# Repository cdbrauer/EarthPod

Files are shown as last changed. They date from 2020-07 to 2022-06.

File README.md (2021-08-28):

# EarthPod
Code for the [EarthPod](https://cdbrauer.github.io/research/index.html#earthpod) environmental sensor pod.

## Datalogging-Arduino

### Hardware

The code in this folder is intended to be used in a sensor pod based on a Adafruit Feather M0 Adalogger. Connected sensors include:

| Sensor | [V1](https://github.com/cdbrauer/EarthPod/tree/master/Datalogging-Arduino/feather-sensor-logging-v1) | [V2](https://github.com/cdbrauer/EarthPod/tree/master/Datalogging-Arduino/feather-sensor-logging-v2.1) |
| :--- | :---: | :---: |
| RTC | DS3231 | DS3231 |
| Gyroscope | FXAS21002C | FXAS21002C |
| Acclerometer/Magnetometer | FXOS8700 | FXOS8700 |
| Temperature/Humidity | si7021 | SHT21 |
| Air Pressure/Temperature | BME280 | BMP280 or SPL06-007 |
| Light Level | SI1145 | BH1750 |
| Wind Direction | TCS34725 | N/A |
| Wind Speed | Handheld Anemometer | N/A |

### feather-sensor-logging-v1

*Compatible with V1 only*

This program will create a .csv file on the Adalogger's SD card that records the measurements captured by the sensors. This program is only compatible with the Adafruit Feather M0 Adalogger, and will not fit on the Adafruit Feather 32u4 Adalogger due to memory constraints.

### feather-sensor-logging-v2.1

*Compatible with V2 Only*

This program will create a .csv file on the Adalogger's SD card that records the measurements captured by the sensors. This program is only compatible with the Adafruit Feather M0 Adalogger, and will not fit on the Adafruit Feather 32u4 Adalogger due to memory constraints.

### feather-sensor-tests/SPL06-007

Test I2C communication for an SPL06-007 air pressure and temperature sensor.

### feather-sensor-tests/anemometer

Test initialization and interrupts for a wind speed sensor from a [handheld anemometer](https://www.amazon.com/Anemometer-Velocity-Measurement-Thermometer-Windsurfing/dp/B01JOTJMU6/).

## Datalogging-Python

### Hardware

The code in this folder is intended to be used in a sensor pod based on a Raspberry Pi or Google Coral. The primary
sensing hardware is the Coral Environmental Sensor Board, which provides ambient light, barometric pressure, humidity, and temperature measurements. This board is compatible with both the Google Coral and Raspberry Pi. Additional sensors can be connected to the Environmental Sensor Board through a series of Grove connectors.

### enviro\_logging.py

This program will create a .csv file that records the measurements captured by the sensors in the Environmental Sensor
Board.

### enviro\_logging\_wind.py

This program adds functionality for reading wind speed using the sensor from a [handheld anemometer](https://www.amazon.com/Anemometer-Velocity-Measurement-Thermometer-Windsurfing/dp/B01JOTJMU6/).

### enviro\_logging\_wind\_airflow.py

This program adds functionality for reading wind speed using a [F662 Board Mount Airflow Sensor](https://www.degreec.com/pages/f660-662) from Degree Controls.

## MagnetRelease

### MagnetRelease.ino

Arduino program for the twist-release magnet system used to deploy the pod.

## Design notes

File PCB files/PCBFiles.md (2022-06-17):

This folder contains PCB schematics & layout files.

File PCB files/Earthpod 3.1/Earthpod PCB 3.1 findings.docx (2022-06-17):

Earthpod PCB 3.1 findings

1. The boards should be cleaned / blown off before they’re plugged in, to remove loose solder.

This could cause an accidental intermittent short.

Solder balls on controller 2:

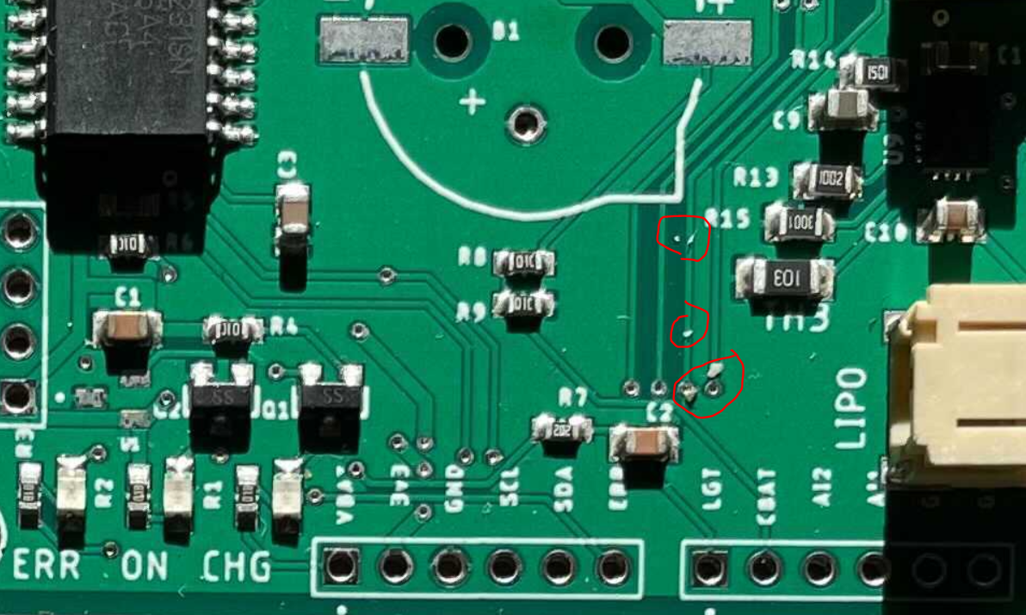
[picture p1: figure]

Solder bridge on controller 8:

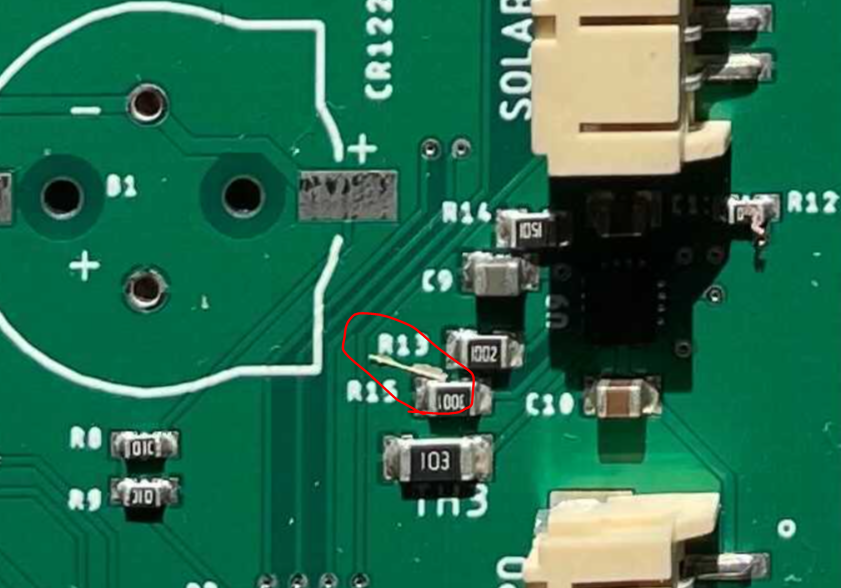
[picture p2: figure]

2. I couldn’t get a good look at this IC on any of the controller boards, but the dot on each chip should be oriented like the markup below (bottom-left corner).

If the dot is not in this orientation, the board should not be plugged in (they messed this up on one board last time).

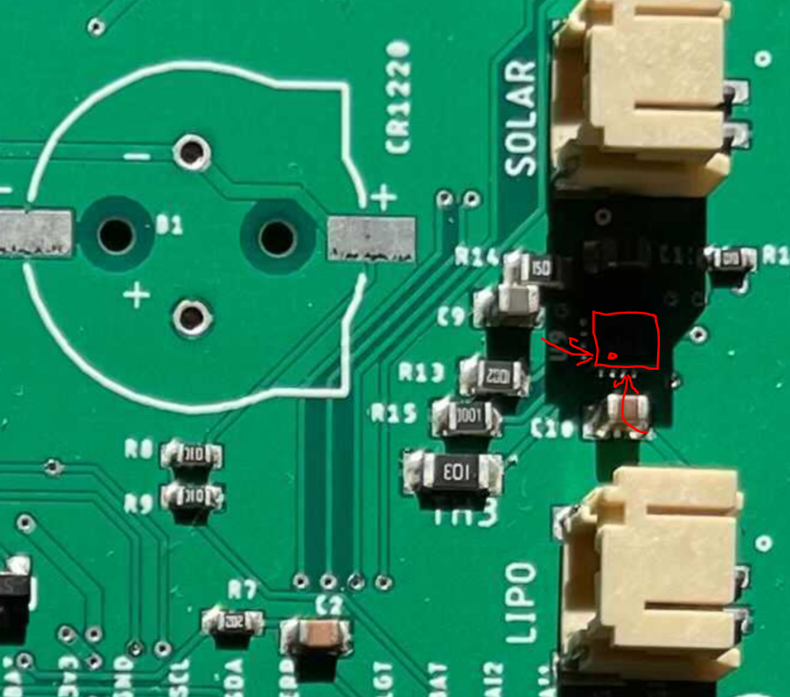
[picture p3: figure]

3. We’ll need to buy a few parts
  - Coin battery connector the RTC
  - Coin battery
  - Hall sensor for the controller board (LEDs will not light up without it)
  - Leaded thermistors for the soil sensor
  - Pin headers

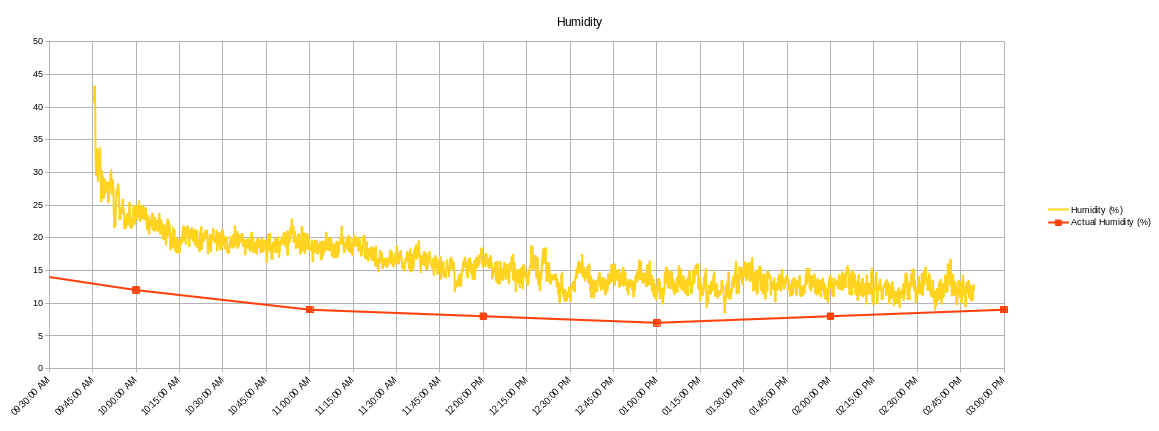
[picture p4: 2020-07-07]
Datalogging-Python/sample-logs/7-6-20/Humidity.png

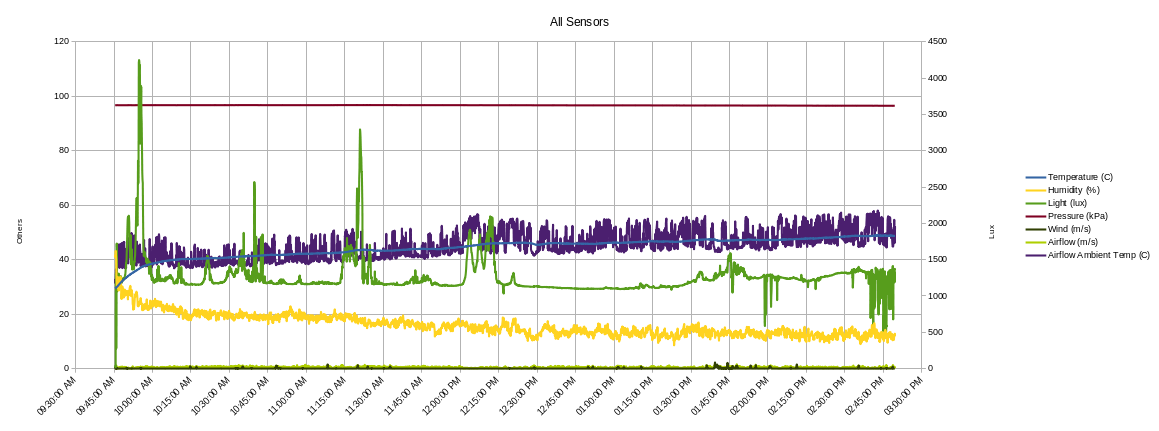
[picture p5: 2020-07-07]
Datalogging-Python/sample-logs/7-6-20/All Sensors.png

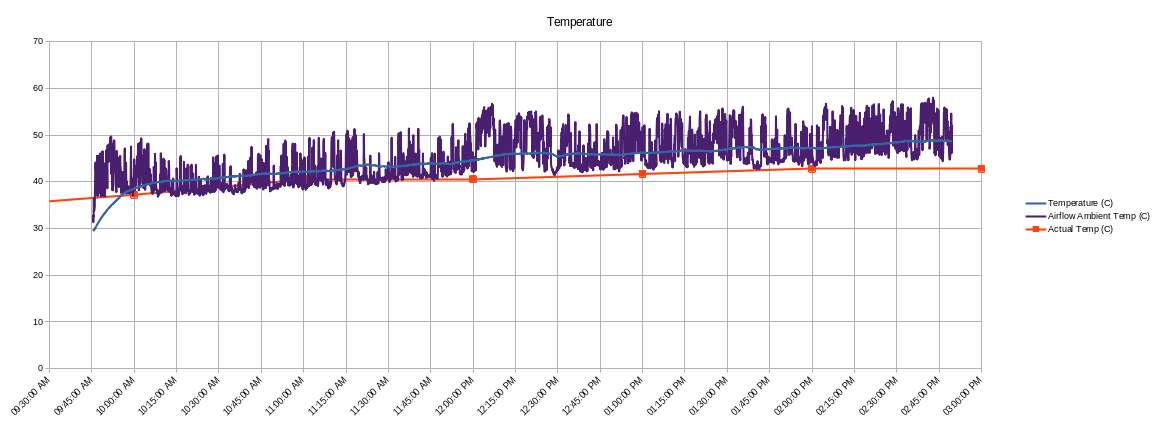
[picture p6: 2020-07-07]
Datalogging-Python/sample-logs/7-6-20/Temperature.png

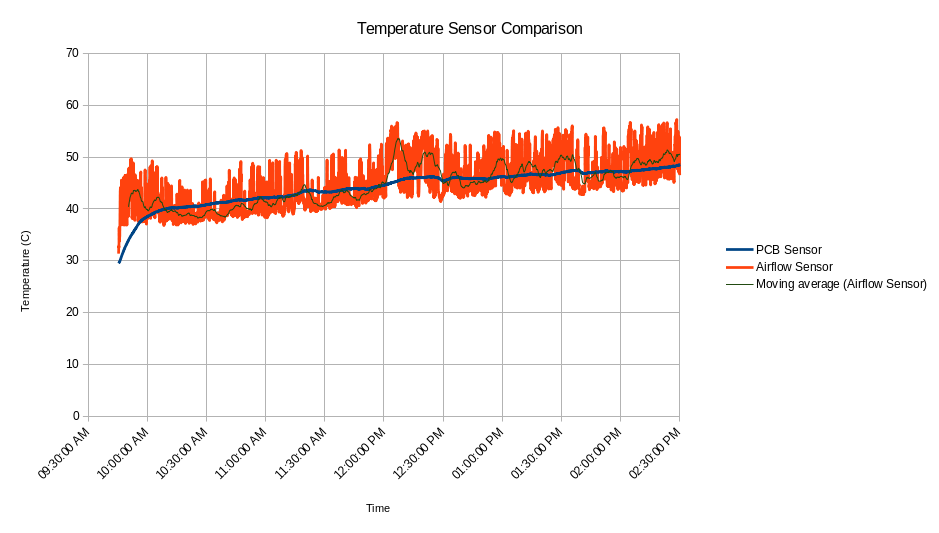
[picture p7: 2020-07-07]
Datalogging-Python/sample-logs/7-6-20/Temp Sensor Comparison.png

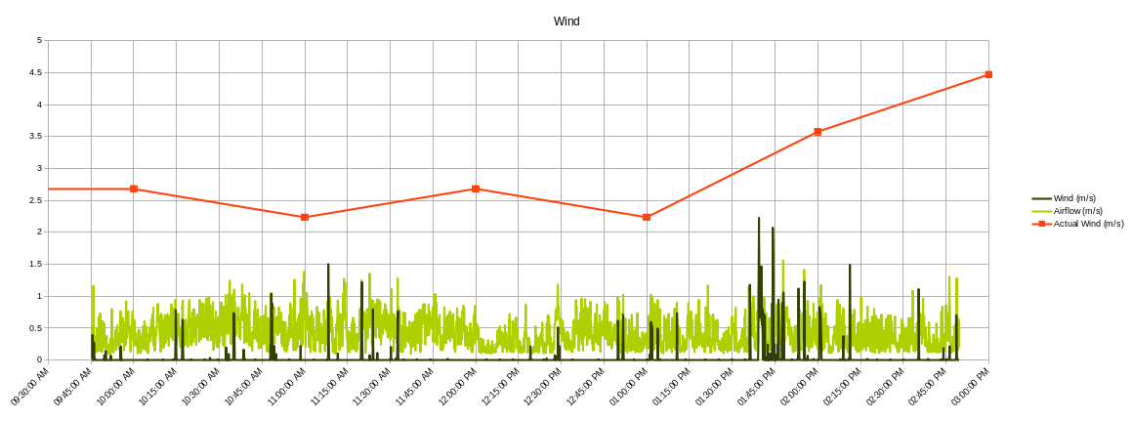
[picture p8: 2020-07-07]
Datalogging-Python/sample-logs/7-6-20/Wind.png

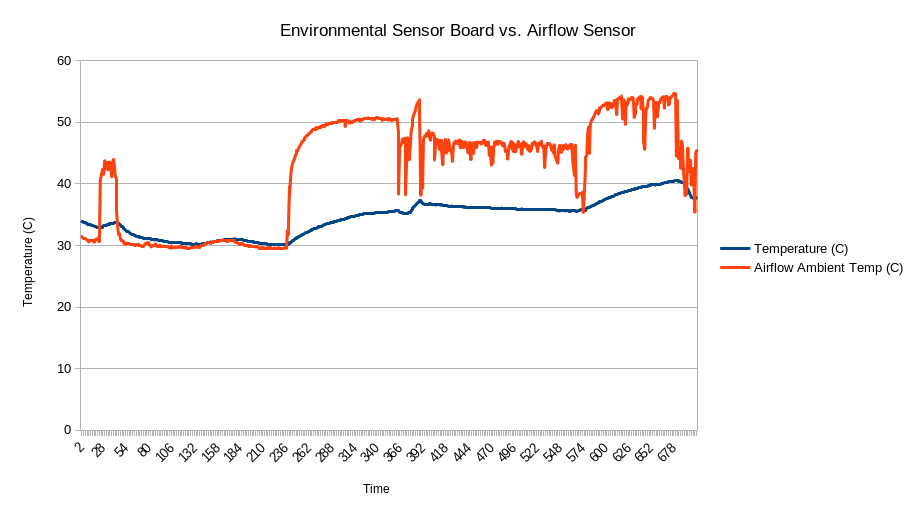
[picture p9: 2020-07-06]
Datalogging-Python/sample-logs/7-5-20/Environmental Sensor Board vs. Airflow Sensor.png

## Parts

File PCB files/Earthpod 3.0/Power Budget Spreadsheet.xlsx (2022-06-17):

DISCHARGING PARAMETERS |  |  |  |  |  |  | CHARGING PARAMETERS
Component | Mfg. Part Number | Voltage (V) | Typical current (mA) | Typical power (mW) | Peak current (mA) | Peak power (mW) | VBAT voltage | Charging current (mA) | Input Power (mW)
Microcontroller | ATSAMD21G18 | 3.3 | 10 | 33 | 98 | 323.4 | 4.2 | 250 | 1050
Wifi Module | ATWINC1500 | 3.3 | 12 | 39.6 | 200 | 660
RTC | DS3231 | 3.3 | 0.2 | 0.66 | 0.2 | 0.66
SD Card* | Any MicroSD card | 3.3 | 30 | 99 | 60 | 198
1 LED | N/A | 3.3 | 0 | 0 | 3.3 | 10.89
Pressure Sensor | SPL06-007 | 3.3 | 0.5 | 1.65 | 0.5 | 1.65
Humidity Sensor | SI7021-A20 | 3.3 | 4 | 13.2 | 4 | 13.2
Gyroscope | FXAS21002C | 3.3 | 2.7 | 8.91 | 2.7 | 8.91
Accelerometer | FXOS8700CQ | 3.3 | 0.575 | 1.8975 | 0.575 | 1.8975
Soil Moisture Sensor | TBD - will be multi-component circuit | 3.3 | 5 | 16.5 | 10 | 33
Light Sensor | TBD | 3.3 | 25 | 82.5 | 25 | 82.5
TOTAL |  |  | 89.975 | 296.9175 | 404.275 | 1334.1075
*SD Card current limits are configurable. 30-60mA is typical. Most mfgrs. do not list current consumption spec.
Here is a good stackexchange post on SD card power consumption. (https://electronics.stackexchange.com/questions/247734/what-determines-the-actual-power-consumption-of-writing-to-a-microsd-card)

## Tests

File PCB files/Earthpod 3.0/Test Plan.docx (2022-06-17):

THINGS TO TEST

Check for shorts to ground from +3.3V, VBAT, VIN, VLIPO

Check IC orientations

One IC is off 90 degrees.

Some silkscreen information missing.

Check for solder bridges

Solar Circuit

- Characterize the VIN signal from the solar panel when in varying amounts of light – is there a lot of fluctuation?
  - Do this with and without the battery.
  - When VIN is around 4.3V or less, DPMM starts. It shouldn’t go lower than this.
- Check that the CHG LED works
- How long will the battery last? Long term test needed.
  - Proper test with solar panels needs to happen in AZ with the housing
  - For now, I can run it in a corner with a fully charged battery and see how long it takes to drain with passive measurements.

Hall Sensor & status LED

- Try magnet in both orientations – do the LEDs turn off when expected?

Moisture Sensor

- Confirm 2.5MHz oscillation
- Test in air and in water, measure the total voltage deflection.
  - Use a wet towel instead of immersing the PCB
  - Adjust resistor values if needed. 1k-10k possible range?
  - Soil capacitance MIGHT range from 1pf to 500 pf
- Are the filters appropriately designed?

Air | No Added Water | Medium Wetness | Lots of water | Just Water | baked

Upload software, change to support new analog signals (2 soil moisture, 2 soil temp, 1 light)

Test humidity sensor with mux

Test Light Sensor analog input

Install temp sensors, test them

Build a sensor network

- Start with a client/server configuration. Scale it up so that any number of sensors (2-4 I guess) can be used.
- Test Wifi power consumption – if continuously streaming, will the battery get drained?

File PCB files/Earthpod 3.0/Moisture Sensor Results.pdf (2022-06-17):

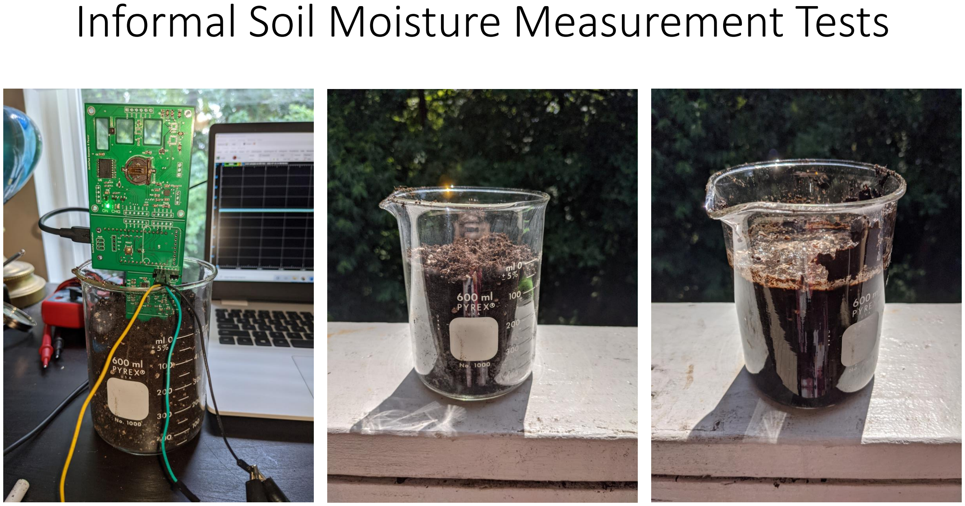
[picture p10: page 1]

Informal Soil Moisture Measurement Tests

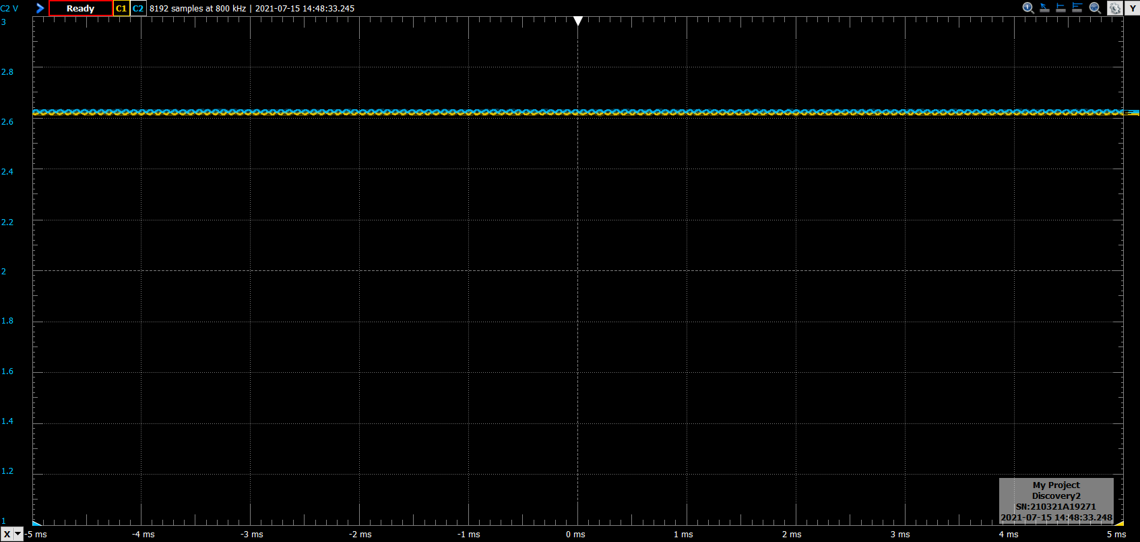
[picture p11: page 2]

Measurement in air – 2.6V

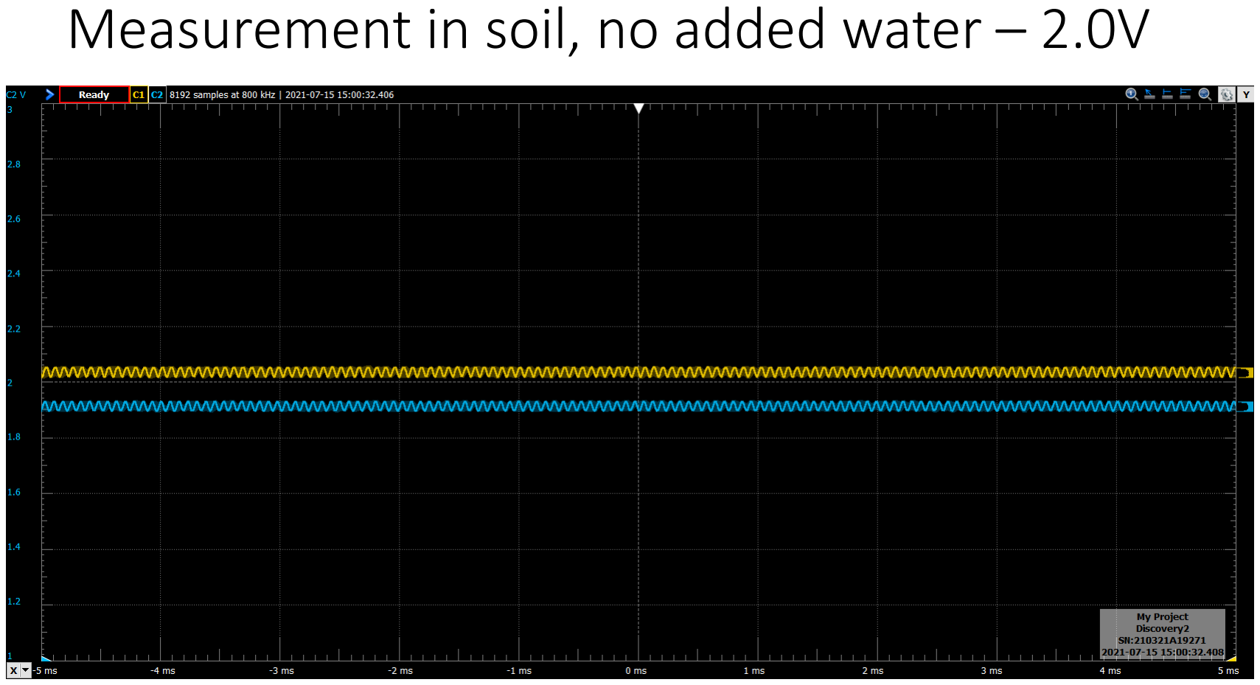
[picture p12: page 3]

Measurement in soil, no added water – 2.0V

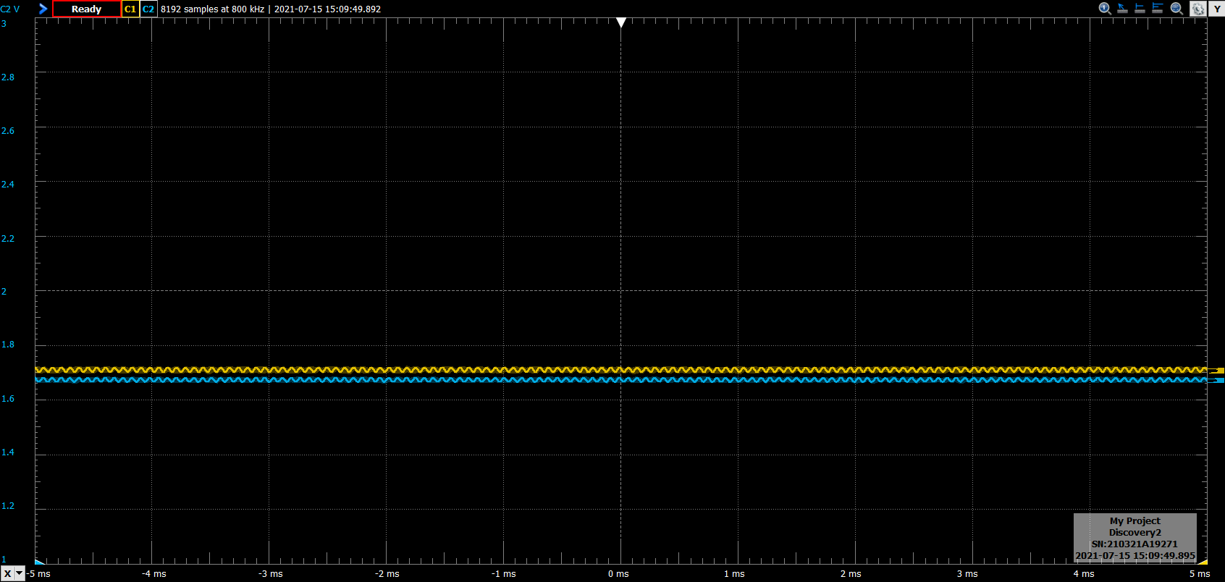
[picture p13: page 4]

Measurement in soil, 150ml water – 1.7V

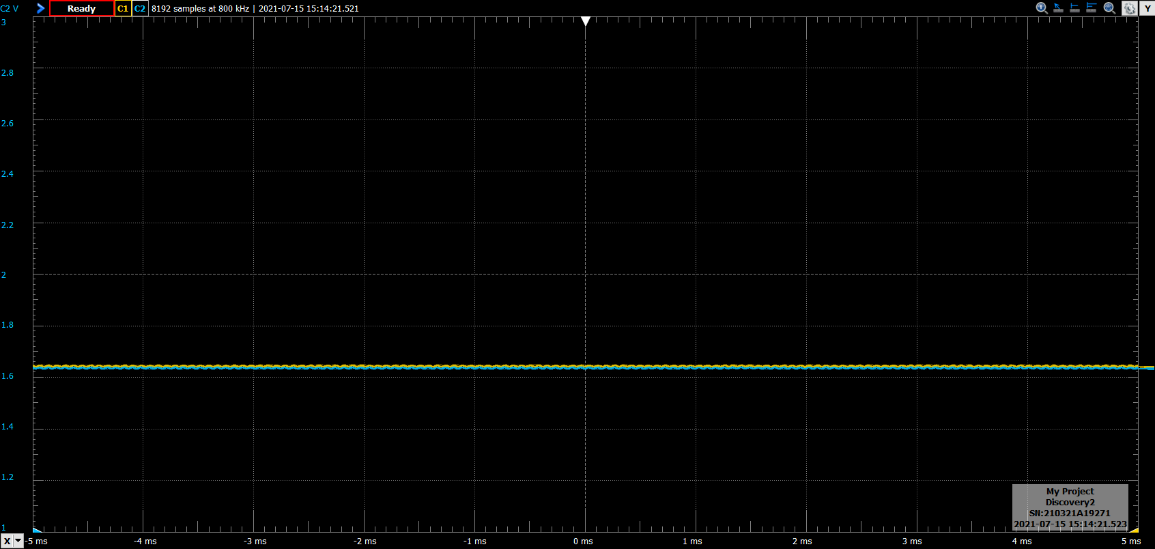
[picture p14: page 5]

Measurement in soil, 300ml water – 1.64V

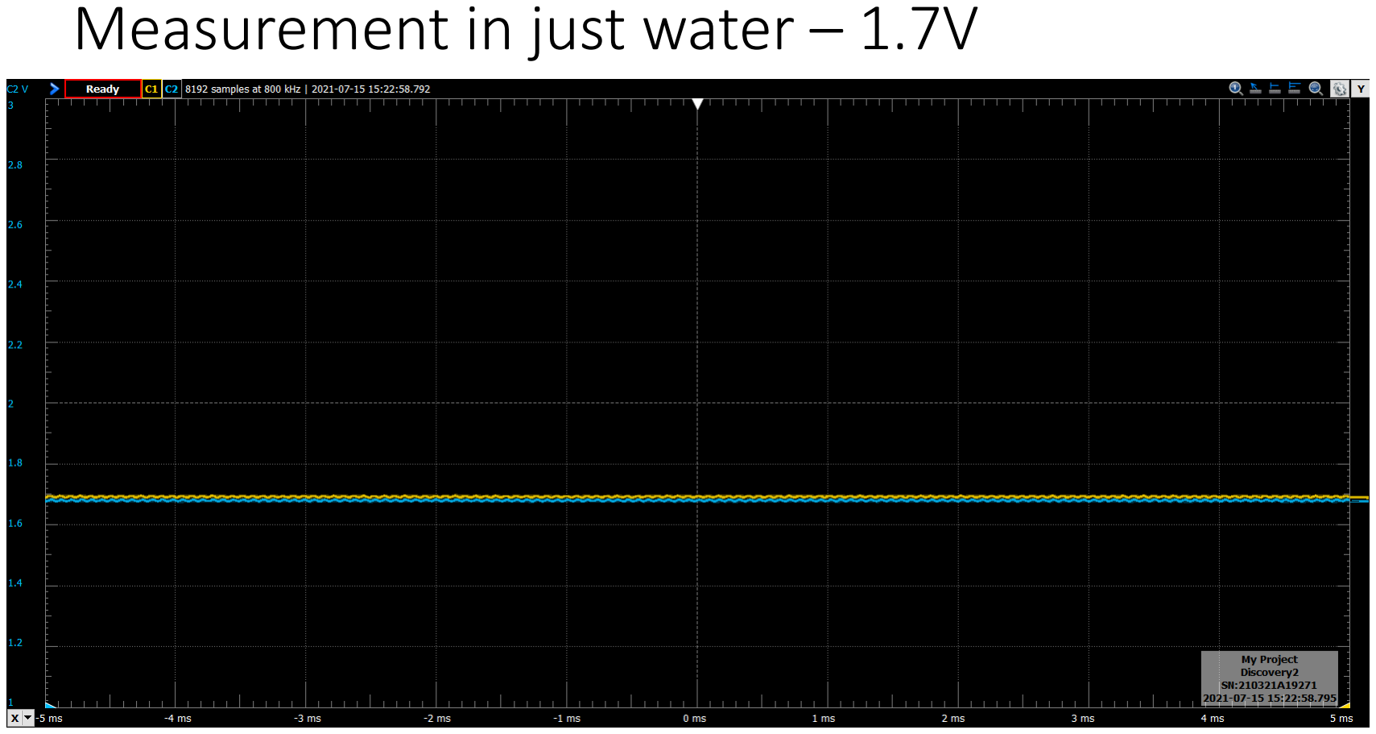
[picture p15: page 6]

Measurement in just water – 1.7V

Measurement after baking – 2.4V

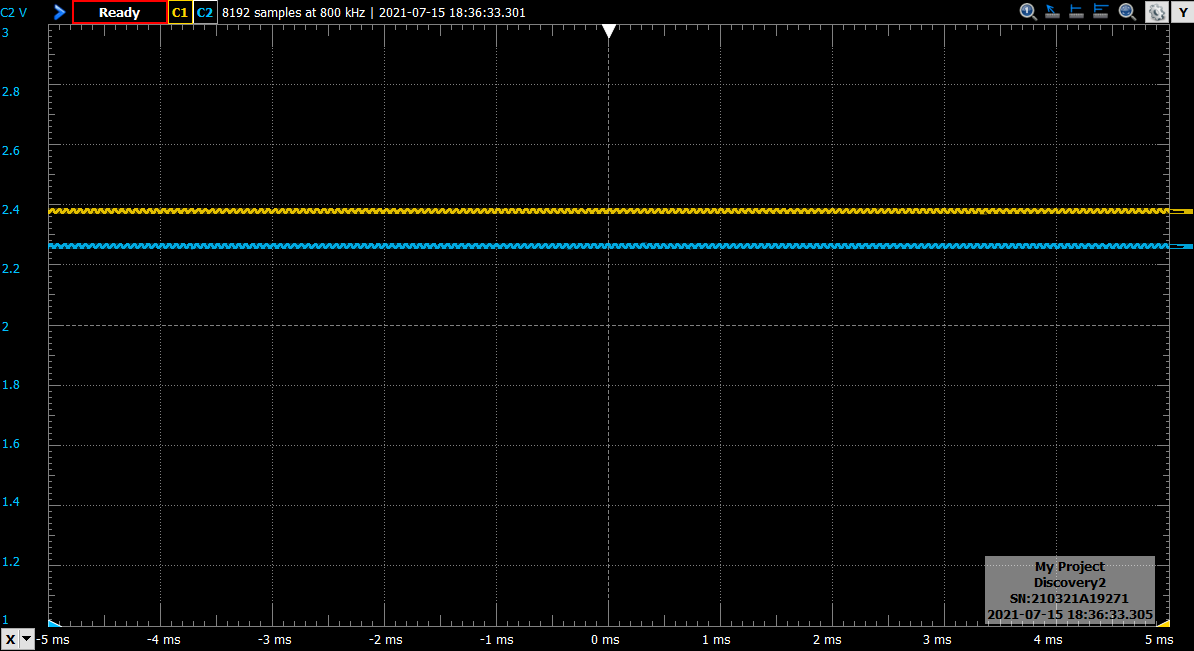
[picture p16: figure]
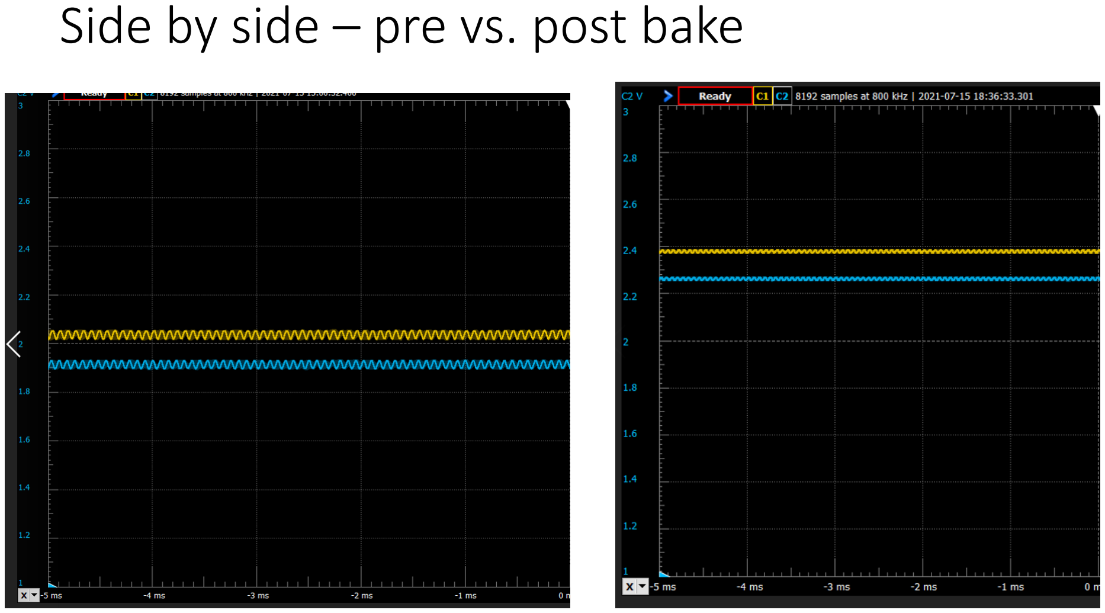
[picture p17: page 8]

Side by side – pre vs. post bake

Details

- Next week:
- Program in Wi-Fi sensor network
- Develop calibration procedure
- Question: will we have some kind of router out in the field?
- Will one pod act as the server, and if so, will storage space for data be an issue?
- Will we just put a laptop out there?
- Decision made: funnel data to a Thingspeak server

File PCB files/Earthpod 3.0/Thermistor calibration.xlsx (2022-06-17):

Temp, C | Resistance, Ohms | Ref. Resistor | Ref. Voltage | Voltage Out | Counts
-40 | 156084 | 4700 | 3.3 | 0.09646482237 | 119.704075 | -36.67082812 | 119.704075
-35 | 112753 |  |  | 0.1320528211 | 163.8655462 | -34.00601167 | 163.8655462
-30 | 82344 |  |  | 0.1781857451 | 221.112311 | -30.68748619 | 221.112311
-25 | 60765 |  |  | 0.2369204919 | 293.9967922 | -26.67694507 | 293.9967922
-20 | 45288 |  |  | 0.3102744659 | 385.0224054 | -21.99053756 | 385.0224054
-15 | 34075 |  |  | 0.4 | 496.3636364 | -16.7167632 | 496.3636364
-10 | 25872 |  |  | 0.5073269659 | 629.546644 | -11.02144593 | 629.546644
-5 | 19814 |  |  | 0.6326996818 | 785.122787 | -5.132257344 | 785.122787
0 | 15300 |  |  | 0.7755 | 962.325 | 0.6982595728 | 962.325
5 | 11909 |  |  | 0.9338310555 | 1158.799446 | 6.24766778 | 1158.799446
10 | 9340 |  |  | 1.104700855 | 1370.833333 | 11.38792987 | 1370.833333
15 | 7378 |  |  | 1.284153005 | 1593.517139 | 16.11634546 | 1593.517139
20 | 5869 |  |  | 1.46749929 | 1821.03321 | 20.54747567 | 1821.03321
25 | 4700 |  |  | 1.65 | 2047.5 | 24.87375367 | 2047.5
30 | 3788 |  |  | 1.82728558 | 2267.495287 | 29.29737341 | 2267.495287
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

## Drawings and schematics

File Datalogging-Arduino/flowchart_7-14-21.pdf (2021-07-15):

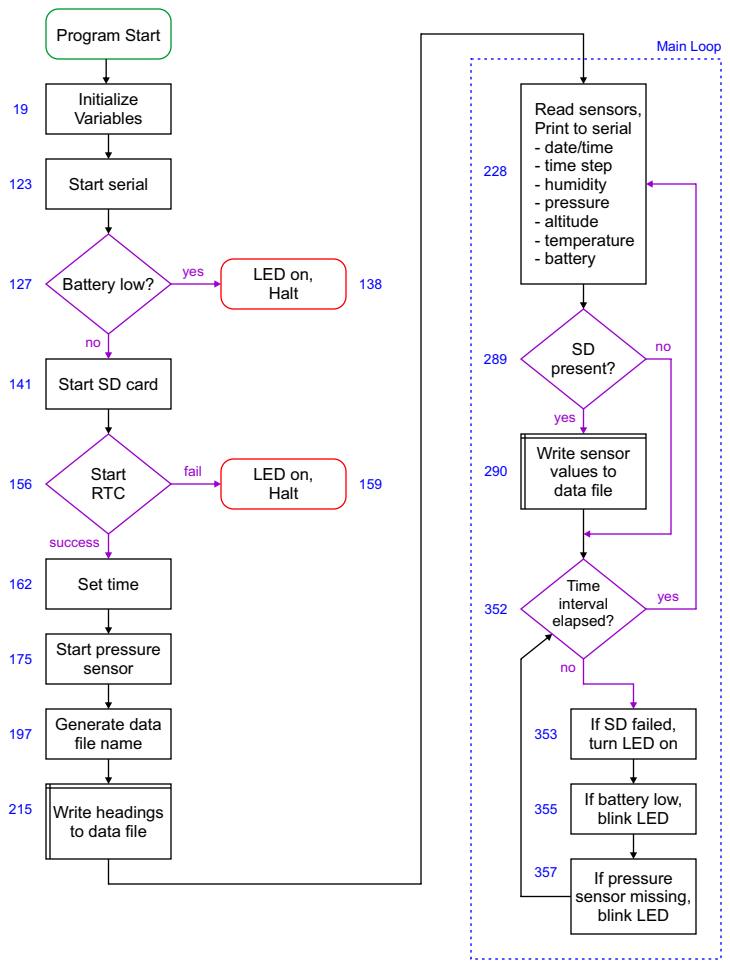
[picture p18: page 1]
Program Start; Initialize Variables; Start serial; Battery low?; LED on,; Halt ¹²⁷; Start SD card; Start RTC; Halt ¹⁵⁶; yes; success; fail; Set time; Start pressure sensor; Main Loop; SD present? ²⁸⁹; Write sensor values to data file; Time interval elapsed?; If pressure sensor missing, blink LED

Read sensors,
Print to serial
- date/time
- time step
- humidity
- pressure
- altitude
- temperature
- battery

Generate data
file name ¹⁹⁷

If SD failed,
turn LED on

If battery low,
blink LED

Write headings
to data file

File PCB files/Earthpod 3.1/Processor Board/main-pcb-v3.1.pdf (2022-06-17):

# GND GND GND 3.3V

## On LED

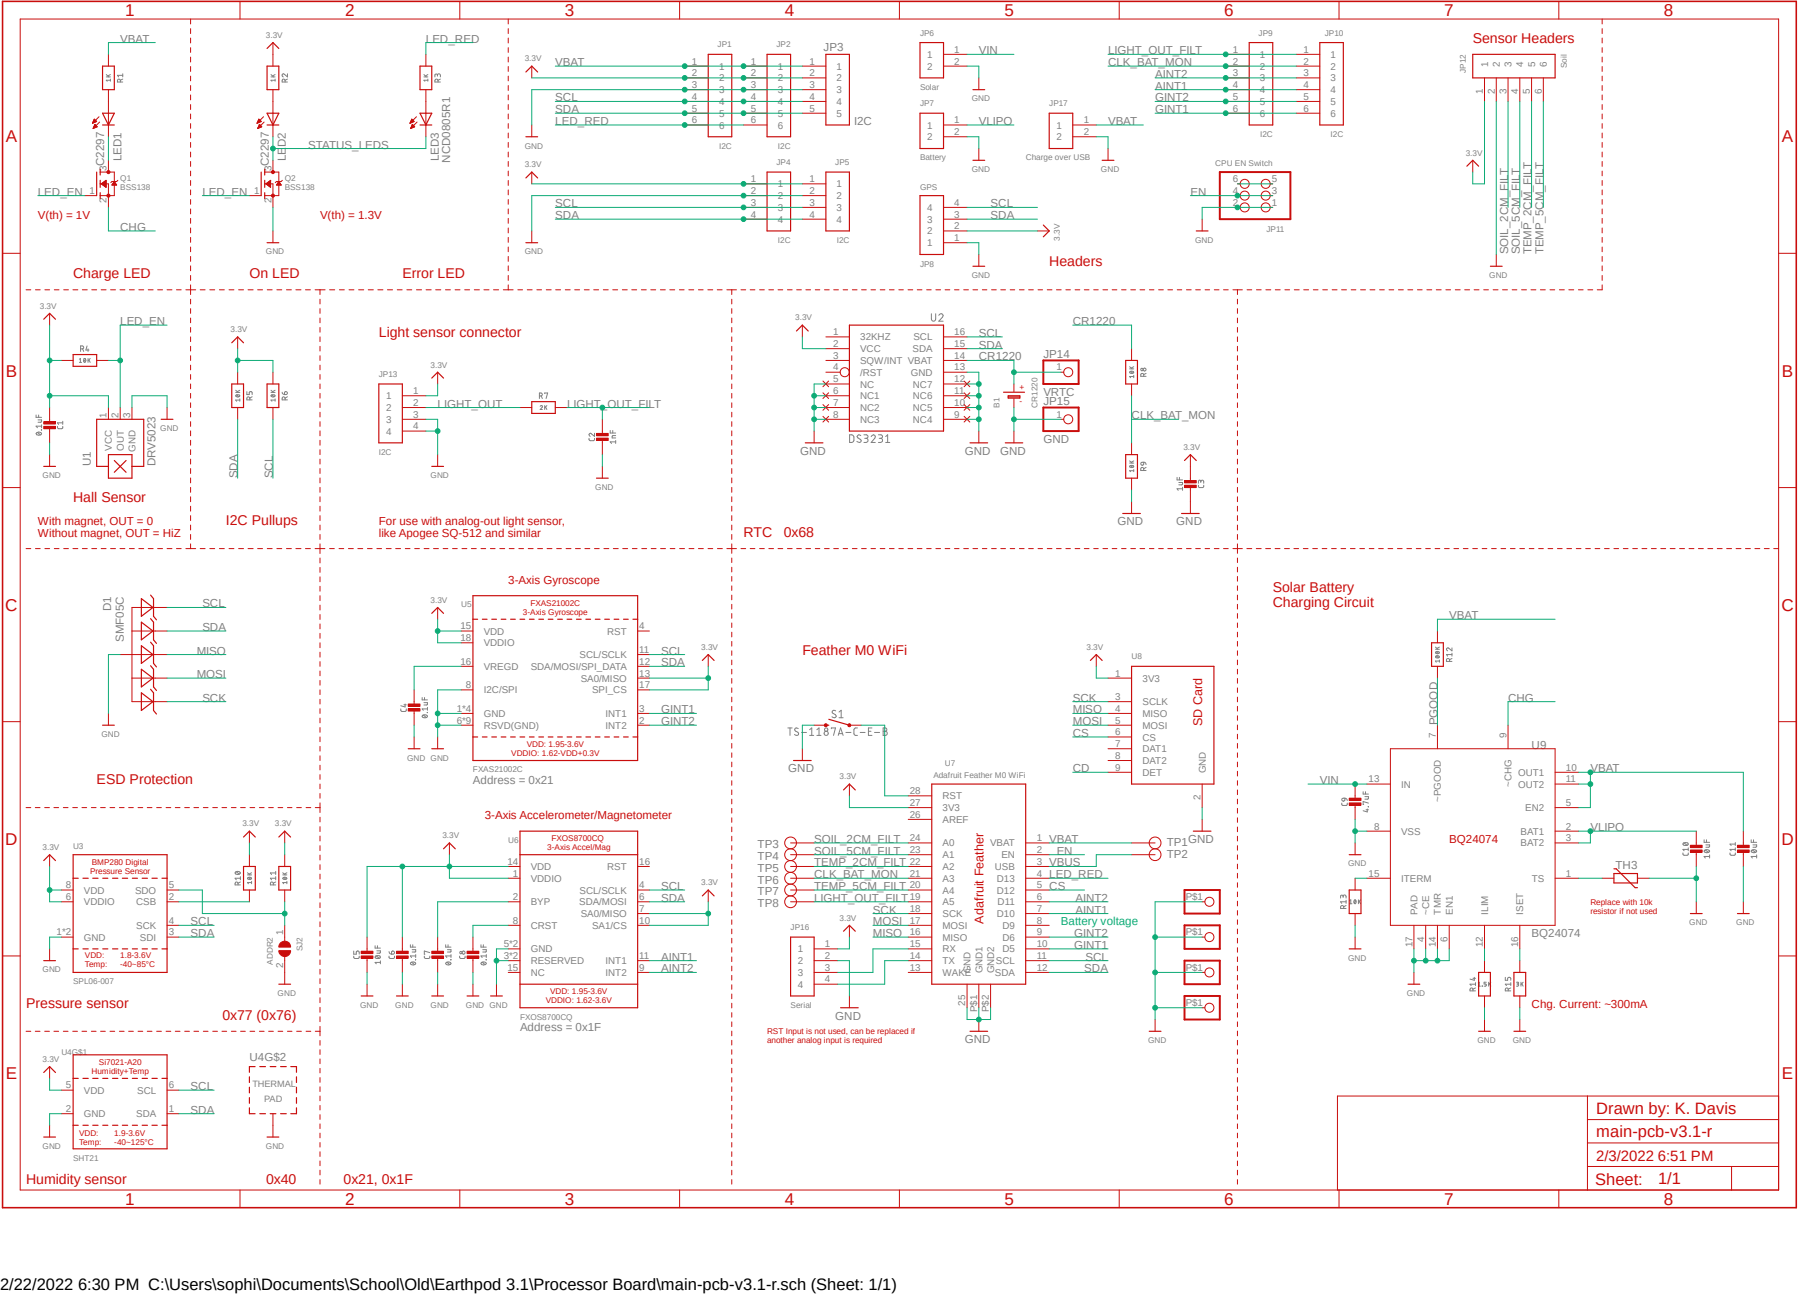
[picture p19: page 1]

Charge over USB GND

With magnet, OUT = 0
Without magnet, OUT = HiZ

For use with analog-out light sensor,
3-Axis Gyroscope VDD: 1.95-3.6V

Feather M0 WiFi
Adafruit Feather M0 WiFi GND

VDDIO: 1.62-VDD+0.3V
3-Axis Accel/Mag VDD: 1.95-3.6V

6 ILIM 12 ISET 16 TS 1 BAT2 3 BAT1 2 EN2 5 OUT2 11 OUT1 10 ~CHG

another analog input is required

2/22/2022 6:30 PM C:\Users\sophi\Documents\School\Old\Earthpod 3.1\Processor Board\main-pcb-v3.1-r.sch (Sheet: 1/1)

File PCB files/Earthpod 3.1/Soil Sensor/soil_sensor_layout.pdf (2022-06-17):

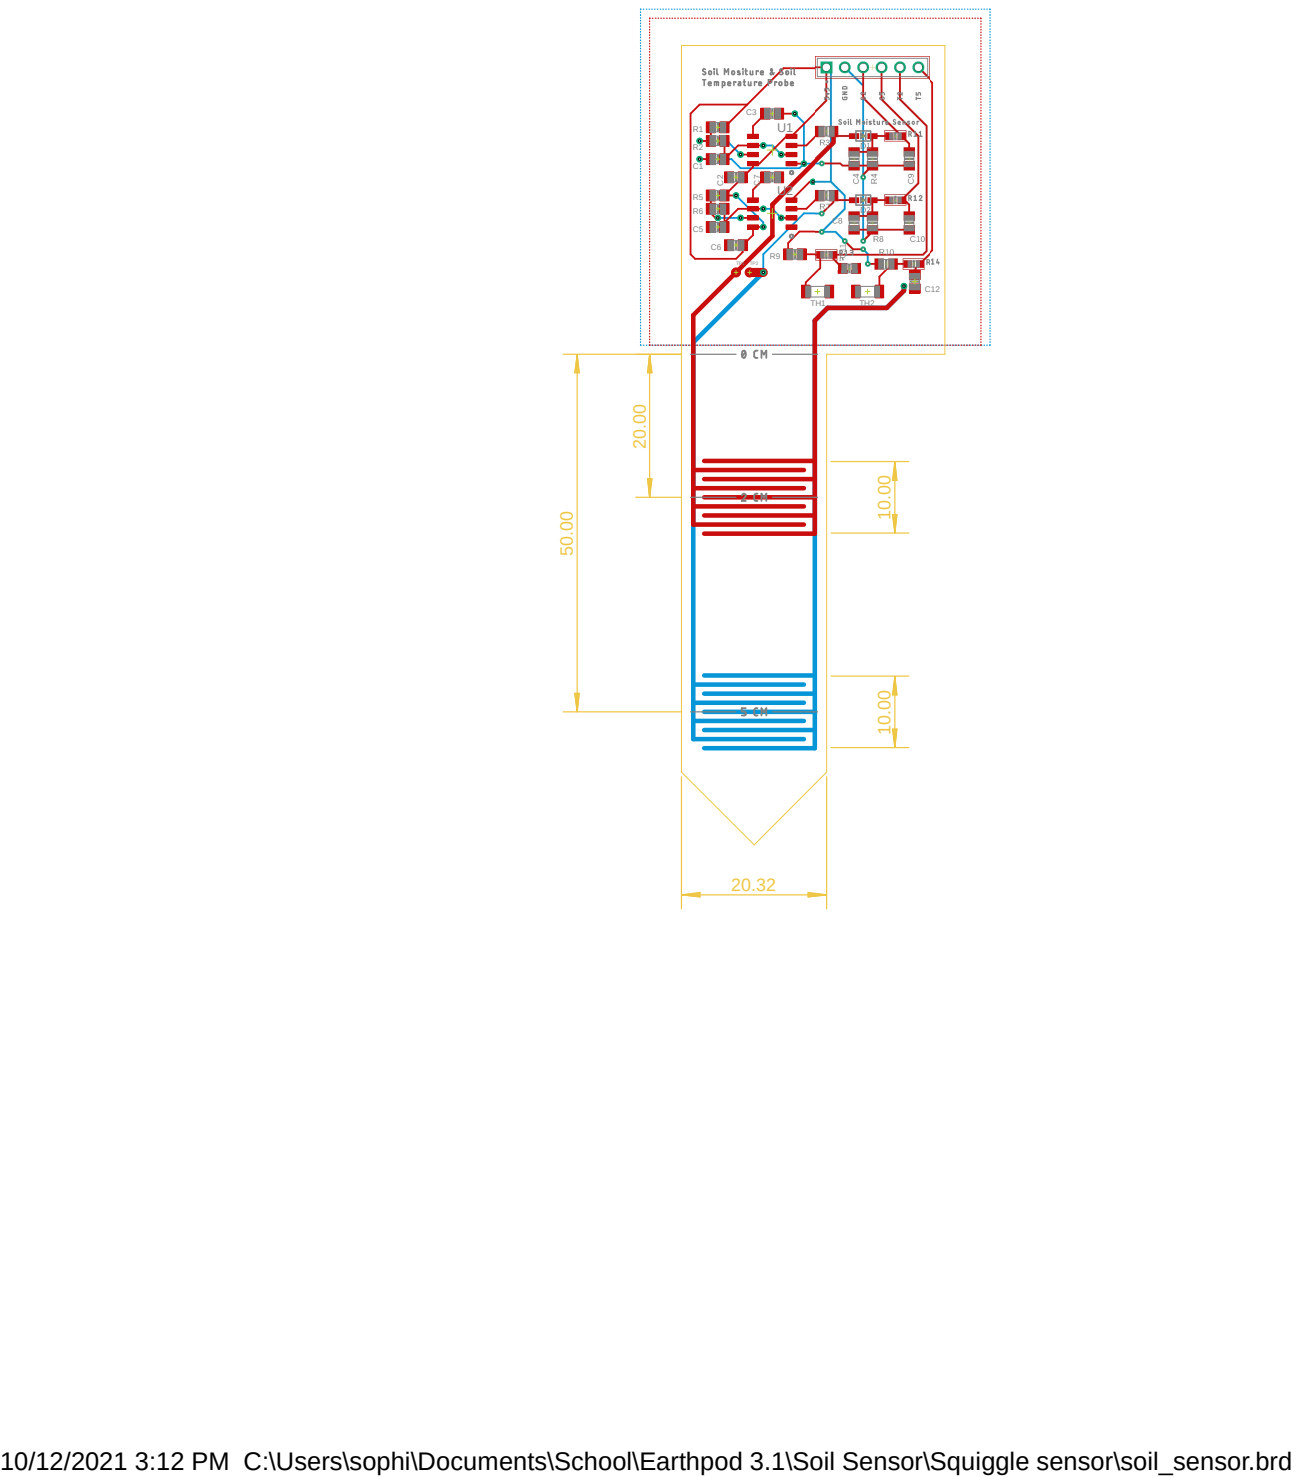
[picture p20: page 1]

10/12/2021 3:12 PM C:\Users\sophi\Documents\School\Earthpod 3.1\Soil Sensor\Squiggle sensor\soil_sensor.brd

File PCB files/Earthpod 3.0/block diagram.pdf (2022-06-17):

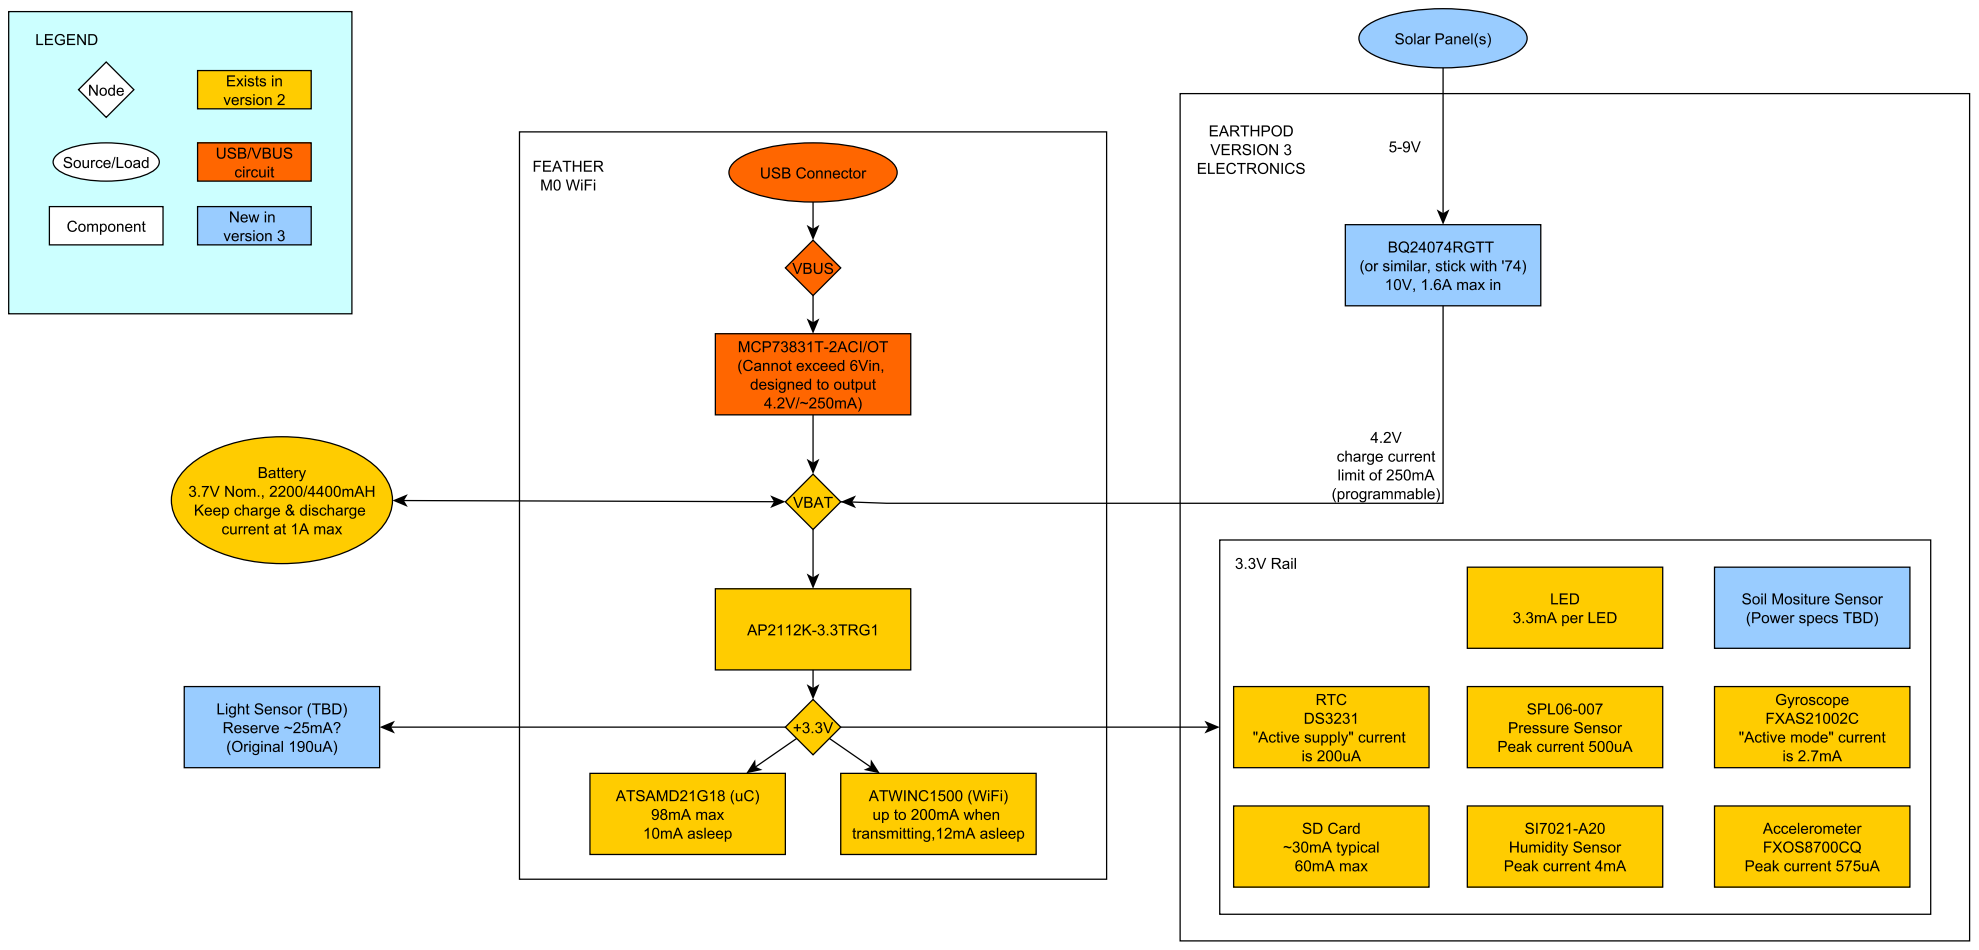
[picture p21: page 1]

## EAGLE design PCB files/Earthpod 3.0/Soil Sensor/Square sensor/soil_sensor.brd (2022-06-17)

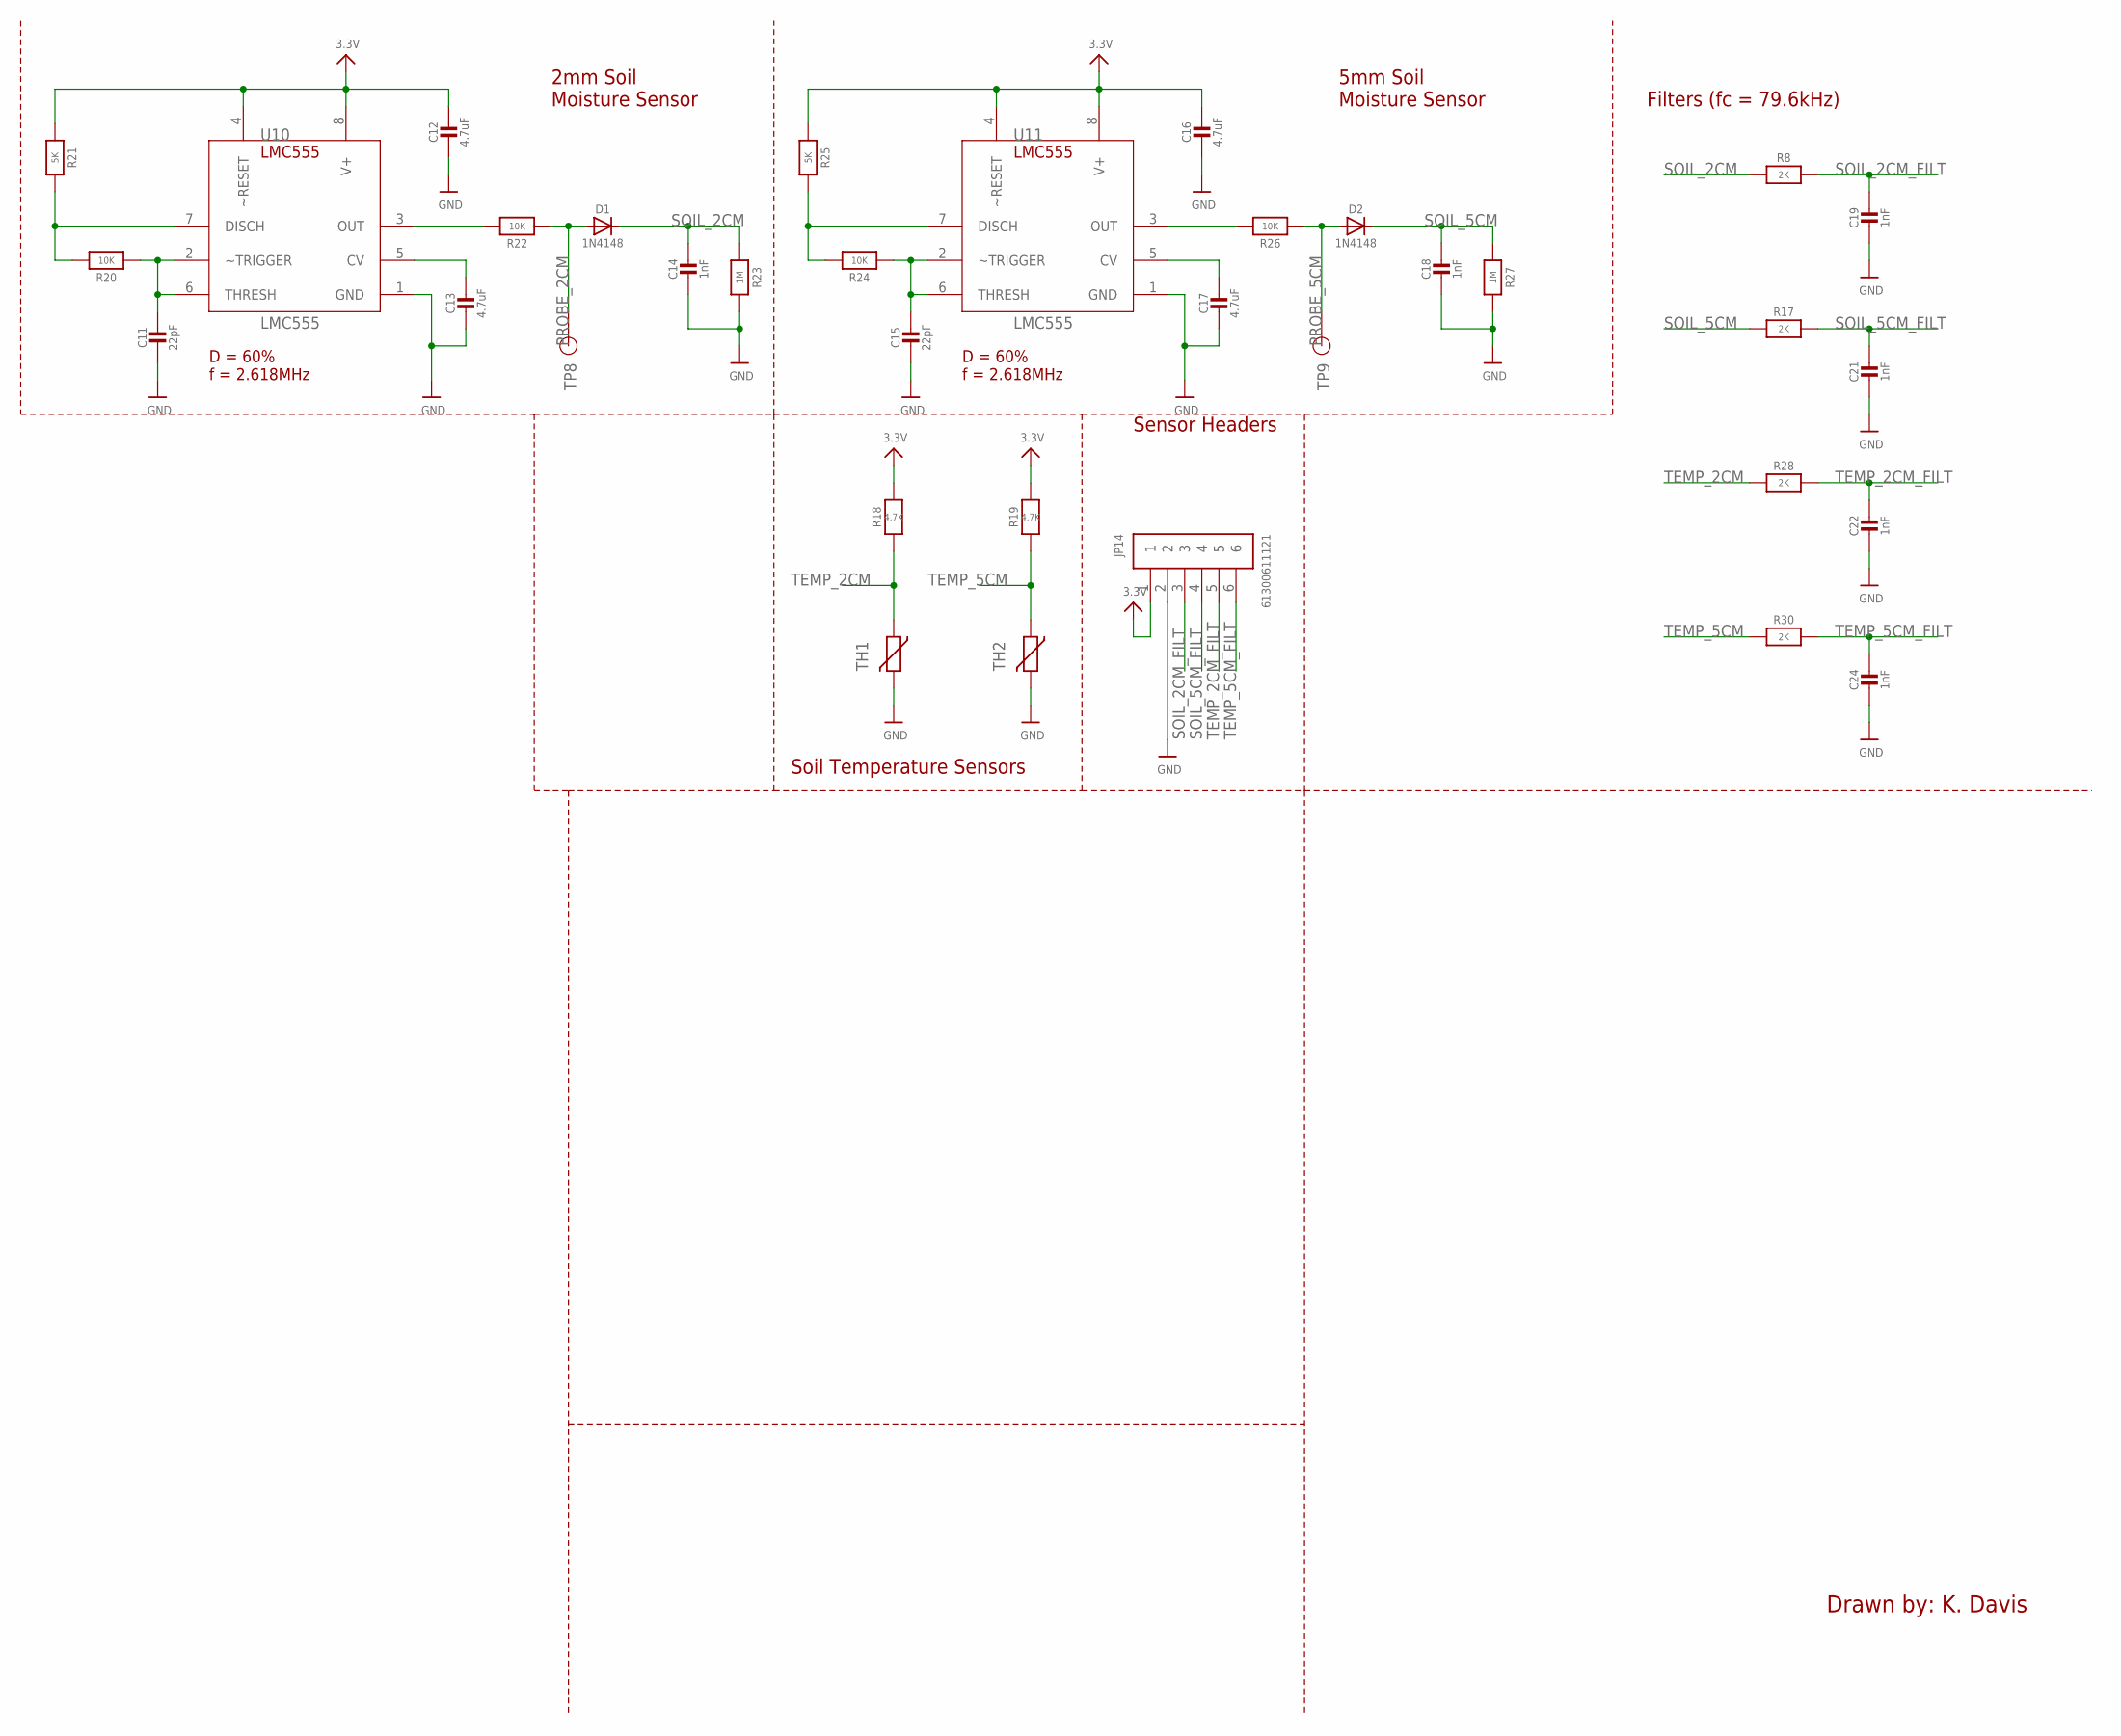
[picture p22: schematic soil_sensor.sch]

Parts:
C11, C15: 22pF; 0805-NO
C12, C13, C16, C17: 4.7uF; 0805-NO
C14, C18, C19, C21, C22, C24: 1nF; 0805-NO
D1, D2: 1N4148; SOD-323
JP14: 61300611121
R8, R17, R28, R30: 2K; 0603-NO
R18, R19: 4.7K; 0805-NO
R20, R22, R24, R26: 10K; 0805-NO
R21, R25: 5K; 0805-NO
R23, R27: 1M; 0805-NO
TH1, TH2: VARISTORCN1206; CT/CN1206
TP8, TP9: TP; TP_50MIL_CIRC
U10, U11: LMC555; SOIC-8

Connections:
3.3V: C12.1, C16.1, JP14.1, R18.2, R19.2, R21.1, R25.1, U10.4 (~RESET), U10.8 (V+), U11.4 (~RESET), U11.8 (V+)
FGD: C11.2, C12.2, C13.2, C14.2, C15.2, C16.2, C17.2, C18.2, C19.2, C21.2, C22.2, C24.2, JP14.2, R23.2, R27.2, TH1.2, TH2.2, U10.1 (GND), U11.1 (GND)
unnamed: C11.1, R20.1, U10.2 (~TRIGGER), U10.6 (THRESH)
unnamed: R20.2, R21.2, U10.7 (DISCH)
unnamed: C13.1, U10.5 (CV)
unnamed: C15.1, R24.1, U11.2 (~TRIGGER), U11.6 (THRESH)
unnamed: R24.2, R25.2, U11.7 (DISCH)
unnamed: R22.2, U10.3 (OUT)
unnamed: C17.1, U11.5 (CV)
unnamed: R26.2, U11.3 (OUT)
PROBE_2CM: D1.A, R22.1, TP8.1
PROBE_5CM: D2.A, R26.1, TP9.1
SOIL_2CM: C14.1, D1.C, R8.1, R23.1
SOIL_2CM_FILT: C19.1, JP14.3, R8.2
SOIL_5CM: C18.1, D2.C, R17.1, R27.1
SOIL_5CM_FILT: C21.1, JP14.4, R17.2
TEMP_2CM: R18.1, R28.1, TH1.1
TEMP_2CM_FILT: C22.1, JP14.5, R28.2
TEMP_5CM: R19.1, R30.1, TH2.1
TEMP_5CM_FILT: C24.1, JP14.6, R30.2

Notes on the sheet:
Soil Temperature Sensors
2mm Soil Moisture Sensor
5mm Soil Moisture Sensor
Filters (fc = 79.6kHz)
Drawn by: K. Davis
D = 60% f = 2.618MHz
Sensor Headers

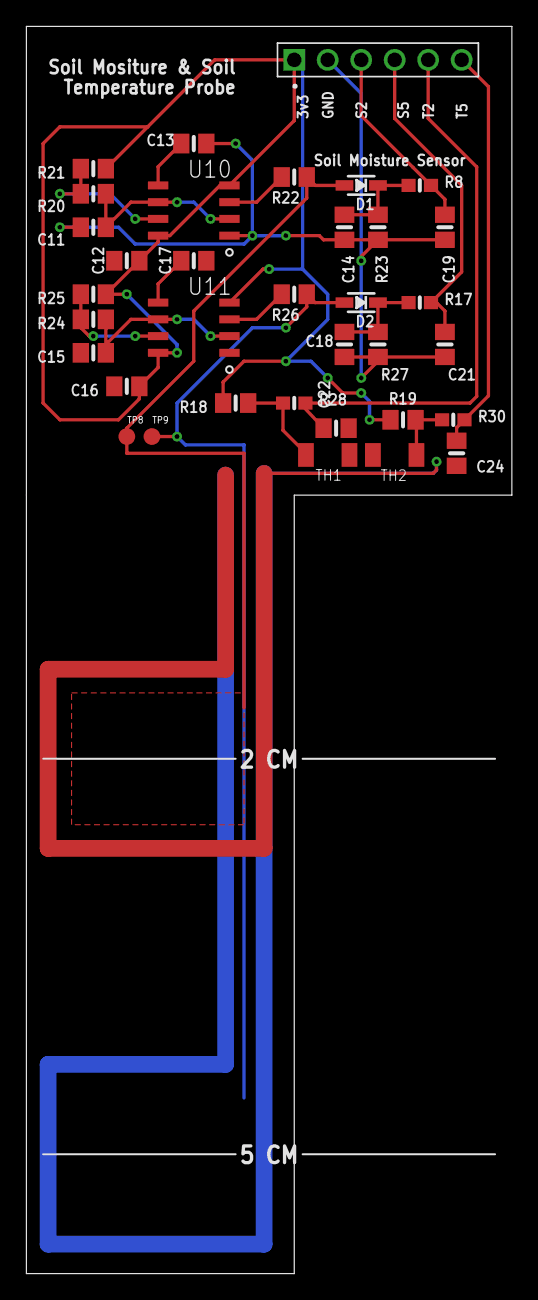
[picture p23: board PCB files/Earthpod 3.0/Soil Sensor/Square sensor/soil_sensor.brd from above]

Board: 2 copper layers, 36.8 x 94.6 mm, 35 parts (0 on the bottom side), 20 nets.

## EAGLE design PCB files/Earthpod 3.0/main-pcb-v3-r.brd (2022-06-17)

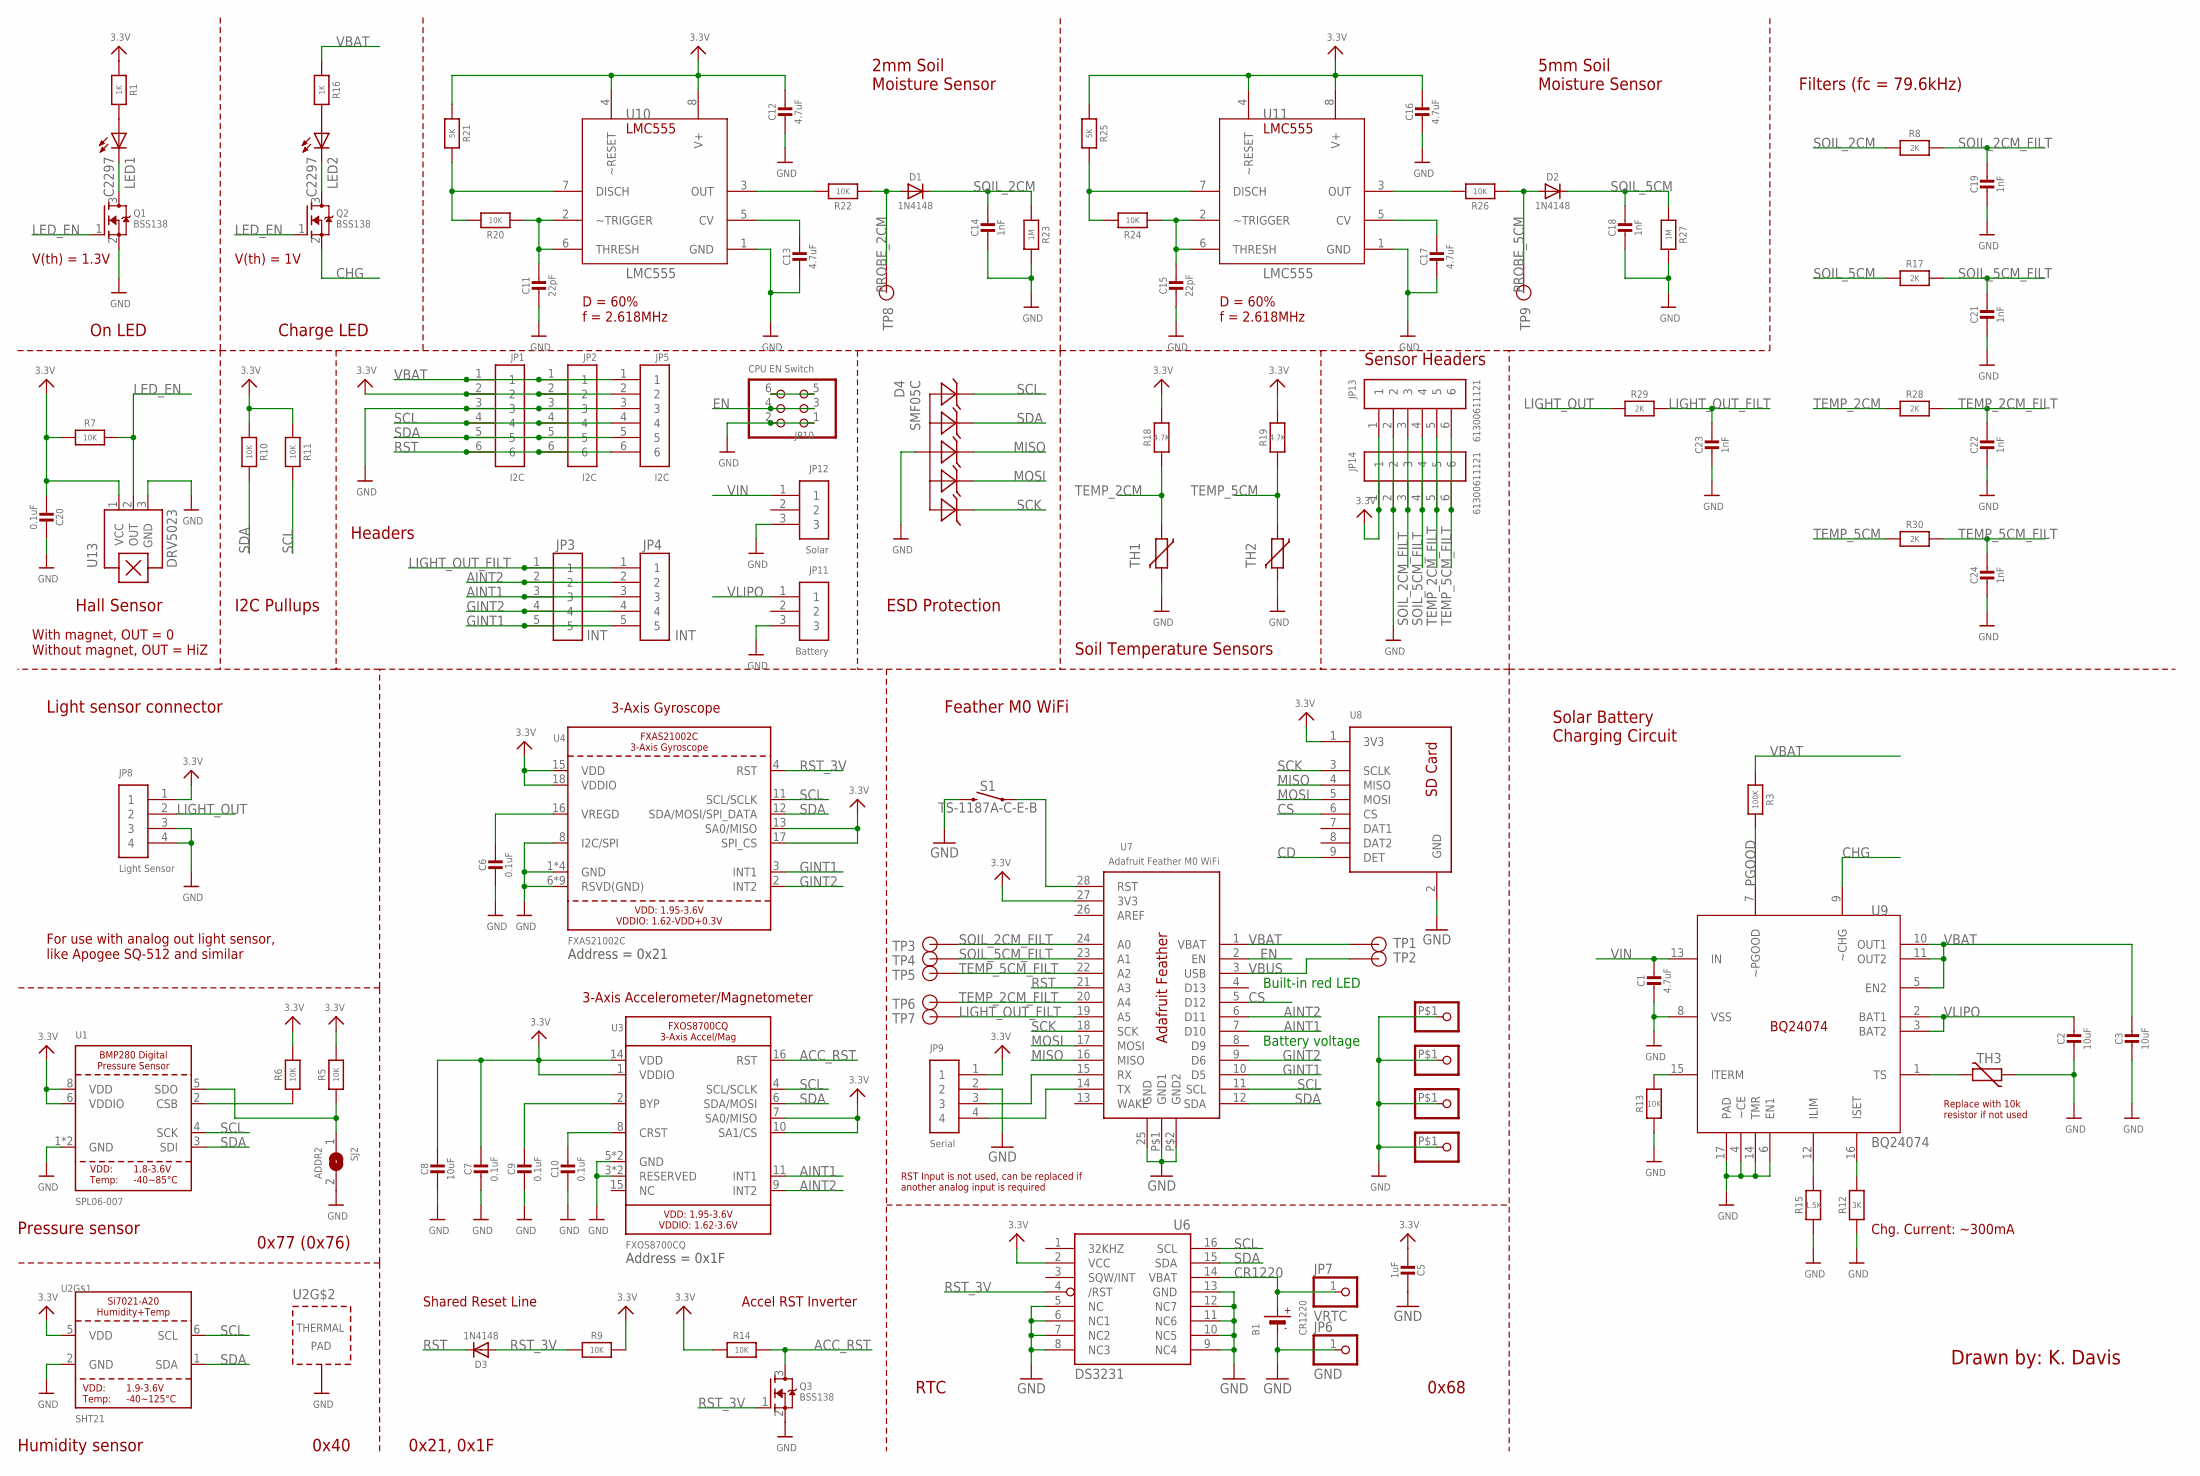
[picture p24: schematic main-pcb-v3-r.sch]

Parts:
B1: CR1220; CR1220-2
C1, C12, C13, C16, C17: 4.7uF; 0805-NO
C2, C3, C8: 10uF; 0805-NO
C5: 1uF; 0805-NO
C6, C7, C9, C10, C20: 0.1uF; 0805-NO
C11, C15: 22pF; 0805-NO
C14, C18, C19, C21, C22, C23, C24: 1nF; 0805-NO
D1, D2, D3: 1N4148; SOD-323
D4: SMF05C; SC70-6
JP1, JP2, JP5: I2C; 61300611121
JP3, JP4: INT; 61300511121
JP6: GND; 1X01_ROUND
JP7: VRTC; 1X01_ROUND
JP8: Light Sensor; 61300411121
JP9: Serial; 61300411121
JP10: CPU EN Switch; 2X03
JP11: Battery; 61300311121
JP12: Solar; 61300311121
JP13, JP14: 61300611121
LED1, LED2: C2297; CHIPLED_0805
Q1, Q2, Q3: BSS138; SOT23-WIDE
R1, R16: 1K; 0603-NO
R3: 100K; 0603-NO
R5, R6, R7, R10, R11: 10K; 0603-NO
R8, R17, R28, R29, R30: 2K; 0603-NO
R9, R13, R14, R20, R22, R24, R26: 10K; 0805-NO
R12: 3K; 0805-NO
R15: 1.5K; 0805-NO
R18, R19: 4.7K; 0805-NO
R21, R25: 5K; 0805-NO
R23, R27: 1M; 0805-NO
S1: TS-1187A-C-E-B; TACTILE_SWITCH_SMD_5.2MM
SJ2: ADDR2; SOLDERJUMPER_ARROW_NOPASTE
TH1, TH2, TH3: VARISTORCN1206; CT/CN1206
TP1, TP2, TP3, TP4, TP5, TP6, TP7, TP8, TP9: TP; TP_50MIL_CIRC
U1: SPL06-007; BMX280_COMBO
U2: SHT21; DFN6_3X3_SI
U3: FXOS8700CQ; QFN16_3MM_FREESCALE_5X3
U4: FXAS21002C; QFN24_4MM_FREESCALE_7X5
U6: DS3231/SO; SO16W
U7: Adafruit Feather M0 WiFi; FEATHER
U8: SDCARD2
U9: BQ24074; VQFN-16_3MM
U10, U11: LMC555; SOIC-8
U13: DRV5023; SOT-23
U$1, U$17, U$19, U$21: MOUNTING

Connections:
3.3V: C5.2, C7.1, C8.1, C12.1, C16.1, C20.2, JP1.2, JP2.2, JP5.2, JP8.1, JP9.1, JP13.1, JP14.1, R1.1, R5.2, R6.2, R7.1, R9.2, R10.1, R11.1, R14.1, R18.2, R19.2, R21.1, R25.1, U1.6 (VDDIO), U1.8 (VDD), U2.5 (VDD), U3.1 (VDDIO), U3.7 (SA0/MISO), U3.10 (SA1/CS), U3.14 (VDD), U4.13 (SA0/MISO), U4.15 (VDD), U4.17 (SPI_CS), U4.18 (VDDIO), U6.2 (VCC), U7.27 (3V3), U8.1 (3V3), U10.4 (~RESET), U10.8 (V+), U11.4 (~RESET), U11.8 (V+), U13.1 (VCC)
ACC_RST: Q3.3 (D), R14.2, U3.16 (RST)
AINT1: JP3.3, JP4.3, U3.11 (INT1), U7.7 (D10)
AINT2: JP3.2, JP4.2, U3.9 (INT2), U7.6 (D11)
CD: U8.9 (DET)
CHG: Q2.2 (S), U9.9 (~CHG)
CR1220: B1.+, JP7.1, U6.14 (VBAT)
CS: U7.5 (D12), U8.6 (CS)
EN: JP10.3, JP10.4, U7.2 (EN)
GINT1: JP3.5, JP4.5, U4.3 (INT1), U7.10 (D5)
GINT2: JP3.4, JP4.4, U4.2 (INT2), U7.9 (D6)
GND: B1.-, C1.2, C2.2, C3.2, C5.1, C6.2, C7.2, C8.2, C9.2, C10.2, C11.2, C12.2, C13.2, C14.2, C15.2, C16.2, C17.2, C18.2, C19.2, C20.1, C21.2, C22.2, C23.2, C24.2, D4.2 (A), JP1.3, JP2.3, JP5.3, JP6.1, JP8.3, JP8.4, JP9.2, JP10.1, JP10.2, JP11.3, JP12.3, JP13.2, JP14.2, Q1.2 (S), Q3.2 (S), R12.1, R13.1, R15.1, R23.2, R27.2, S1.3 (2), SJ2.2, TH1.2, TH2.2, TH3.2, U1.1 (GND), U1.7 (GND), U2.2 (GND), U2.PAD (TP), U3.3 (RESERVED), U3.5 (GND), U3.12 (GND), U3.13 (RESERVED), U4.1 (GND), U4.5 (GND), U4.6 (RSVD(GND)), U4.7 (RSVD(GND)), U4.8 (I2C/SPI), U4.9 (RSVD(GND)), U4.10 (RSVD(GND)), U4.14 (GND), U4.19 (GND), U4.20 (RSVD(GND)), U4.21 (RSVD(GND)), U4.22 (RSVD(GND)), U4.23 (RSVD(GND)), U4.24 (RSVD(GND)), U6.5 (NC), U6.6 (NC1), U6.7 (NC2), U6.8 (NC3), U6.9 (NC4), U6.10 (NC5), U6.11 (NC6), U6.12 (NC7), U6.13 (GND), U7.25 (GND), U7.P$1 (GND1), U7.P$2 (GND2), U8.2 (GND), U9.4 (~CE), U9.6 (EN1), U9.8 (VSS), U9.14 (TMR), U9.17 (PAD), U10.1 (GND), U11.1 (GND), U13.3 (GND), U$1.P$1, U$17.P$1, U$19.P$1, U$21.P$1
ITERM: R13.2, U9.15 (ITERM)
LED1: LED1.C, Q1.3 (D)
LED2: LED2.C, Q2.3 (D)
LED_EN: Q1.1 (G), Q2.1 (G), R7.2, U13.2 (OUT)
LIGHT_OUT: JP8.2, R29.1
LIGHT_OUT_FILT: C23.1, JP3.1, JP4.1, R29.2, TP7.1, U7.19 (A5)
MISO: D4.4 (C3), U7.16 (MISO), U8.4 (MISO)
MOSI: D4.5 (C4), U7.17 (MOSI), U8.5 (MOSI)
unnamed: LED1.A, R1.2
unnamed: R6.1, U1.2 (CSB)
unnamed: R5.1, SJ2.1, U1.5 (SDO)
unnamed: JP9.3, U7.15 (RX)
unnamed: JP10.5, JP10.6
unnamed: JP9.4, U7.14 (TX)
unnamed: TH3.1, U9.1 (TS)
unnamed: S1.1, U7.28 (RST)
unnamed: C11.1, R20.1, U10.2 (~TRIGGER), U10.6 (THRESH)
unnamed: LED2.A, R16.2
unnamed: R20.2, R21.2, U10.7 (DISCH)
unnamed: C13.1, U10.5 (CV)
unnamed: C15.1, R24.1, U11.2 (~TRIGGER), U11.6 (THRESH)
unnamed: R12.2, U9.16 (ISET)
unnamed: R15.2, U9.12 (ILIM)
unnamed: R24.2, R25.2, U11.7 (DISCH)
unnamed: R22.2, U10.3 (OUT)
unnamed: C17.1, U11.5 (CV)
unnamed: R26.2, U11.3 (OUT)
unnamed: C6.1, U4.16 (VREGD)
unnamed: C9.1, U3.2 (BYP)
unnamed: C10.1, U3.8 (CRST)
PGOOD: R3.2, U9.7 (~PGOOD)
PROBE_2CM: D1.A, R22.1, TP8.1
PROBE_5CM: D2.A, R26.1, TP9.1
RST: D3.C, JP1.6, JP2.6, JP5.6, U7.21 (A3)
RST_3V: D3.A, Q3.1 (G), R9.1, U4.4 (RST), U6.4 (/RST)
SCK: D4.6 (C5), U7.18 (SCK), U8.3 (SCLK)
SCL: D4.1 (C1), JP1.4, JP2.4, JP5.4, R11.2, U1.4 (SCK), U2.6 (SCL), U3.4 (SCL/SCLK), U4.11 (SCL/SCLK), U6.16 (SCL), U7.11 (SCL)
SDA: D4.3 (C2), JP1.5, JP2.5, JP5.5, R10.2, U1.3 (SDI), U2.1 (SDA), U3.6 (SDA/MOSI), U4.12 (SDA/MOSI/SPI_DATA), U6.15 (SDA), U7.12 (SDA)
SOIL_2CM: C14.1, D1.C, R8.1, R23.1
SOIL_2CM_FILT: C19.1, JP13.3, JP14.3, R8.2, TP3.1, U7.24 (A0)
SOIL_5CM: C18.1, D2.C, R17.1, R27.1
SOIL_5CM_FILT: C21.1, JP13.4, JP14.4, R17.2, TP4.1, U7.23 (A1)
TEMP_2CM: R18.1, R28.1, TH1.1
TEMP_2CM_FILT: C22.1, JP13.5, JP14.5, R28.2, TP6.1, U7.20 (A4)
TEMP_5CM: R19.1, R30.1, TH2.1
TEMP_5CM_FILT: C24.1, JP13.6, JP14.6, R30.2, TP5.1, U7.22 (A2)
VBAT: C3.1, JP1.1, JP2.1, JP5.1, R3.1, R16.1, TP1.1, U7.1 (VBAT), U9.5 (EN2), U9.10 (OUT1), U9.11 (OUT2)
VBUS: TP2.1, U7.3 (USB)
VIN: C1.1, JP12.1, U9.13 (IN)
VLIPO: C2.1, JP11.1, U9.2 (BAT1), U9.3 (BAT2)

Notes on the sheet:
I2C Pullups
Headers
On LED
RTC
0x68
ESD Protection
Battery voltage
Built-in red LED
Light sensor connector
Pressure sensor
Humidity sensor
0x40
0x77 (0x76)
Address = 0x21
Address = 0x1F
3-Axis Accelerometer/Magnetometer
3-Axis Gyroscope
Shared Reset Line
Accel RST Inverter
0x21, 0x1F
Chg. Current: ~300mA
Hall Sensor
Soil Temperature Sensors
Charge LED
2mm Soil Moisture Sensor
5mm Soil Moisture Sensor
Filters (fc = 79.6kHz)
Solar Battery Charging Circuit
Feather M0 WiFi
With magnet, OUT = 0 Without magnet, OUT = HiZ
V(th) = 1.3V
V(th) = 1V
Drawn by: K. Davis
D = 60% f = 2.618MHz
Replace with 10k resistor if not used
For use with analog out light sensor, like Apogee SQ-512 and similar
RST Input is not used, can be replaced if another analog input is required
Sensor Headers

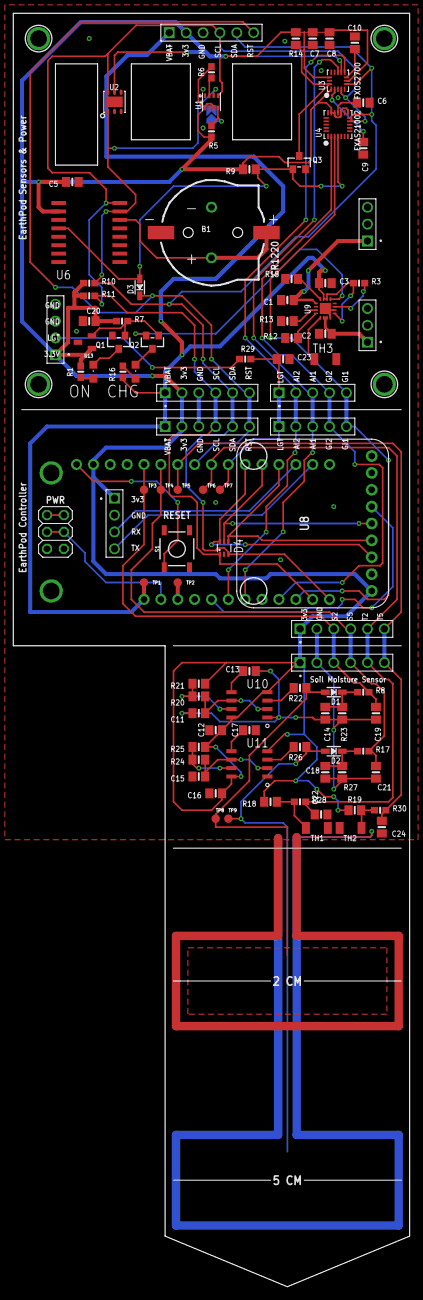
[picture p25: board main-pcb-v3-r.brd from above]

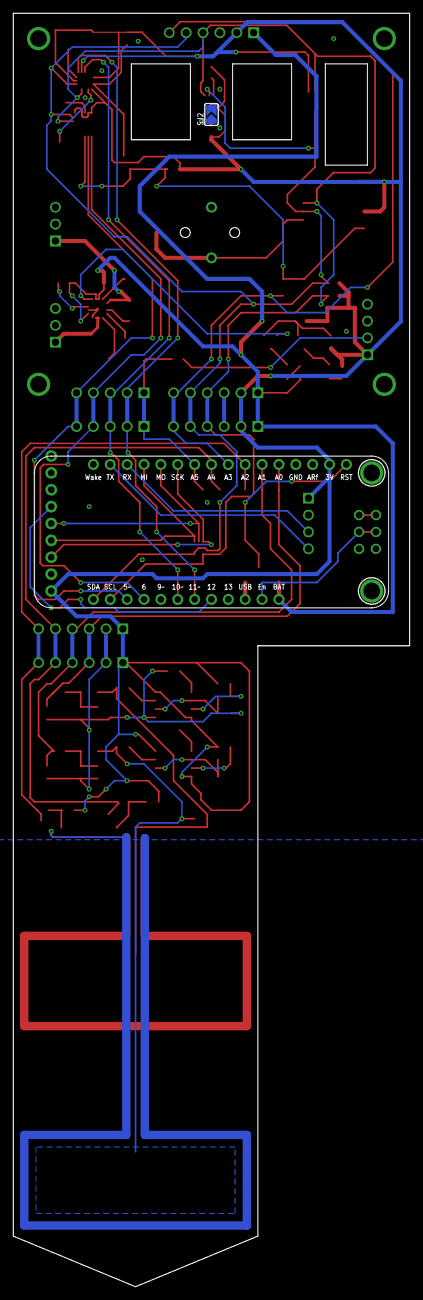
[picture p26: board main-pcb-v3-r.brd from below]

Board: 2 copper layers, 59.7 x 191.8 mm, 104 parts (2 on the bottom side), 61 nets.

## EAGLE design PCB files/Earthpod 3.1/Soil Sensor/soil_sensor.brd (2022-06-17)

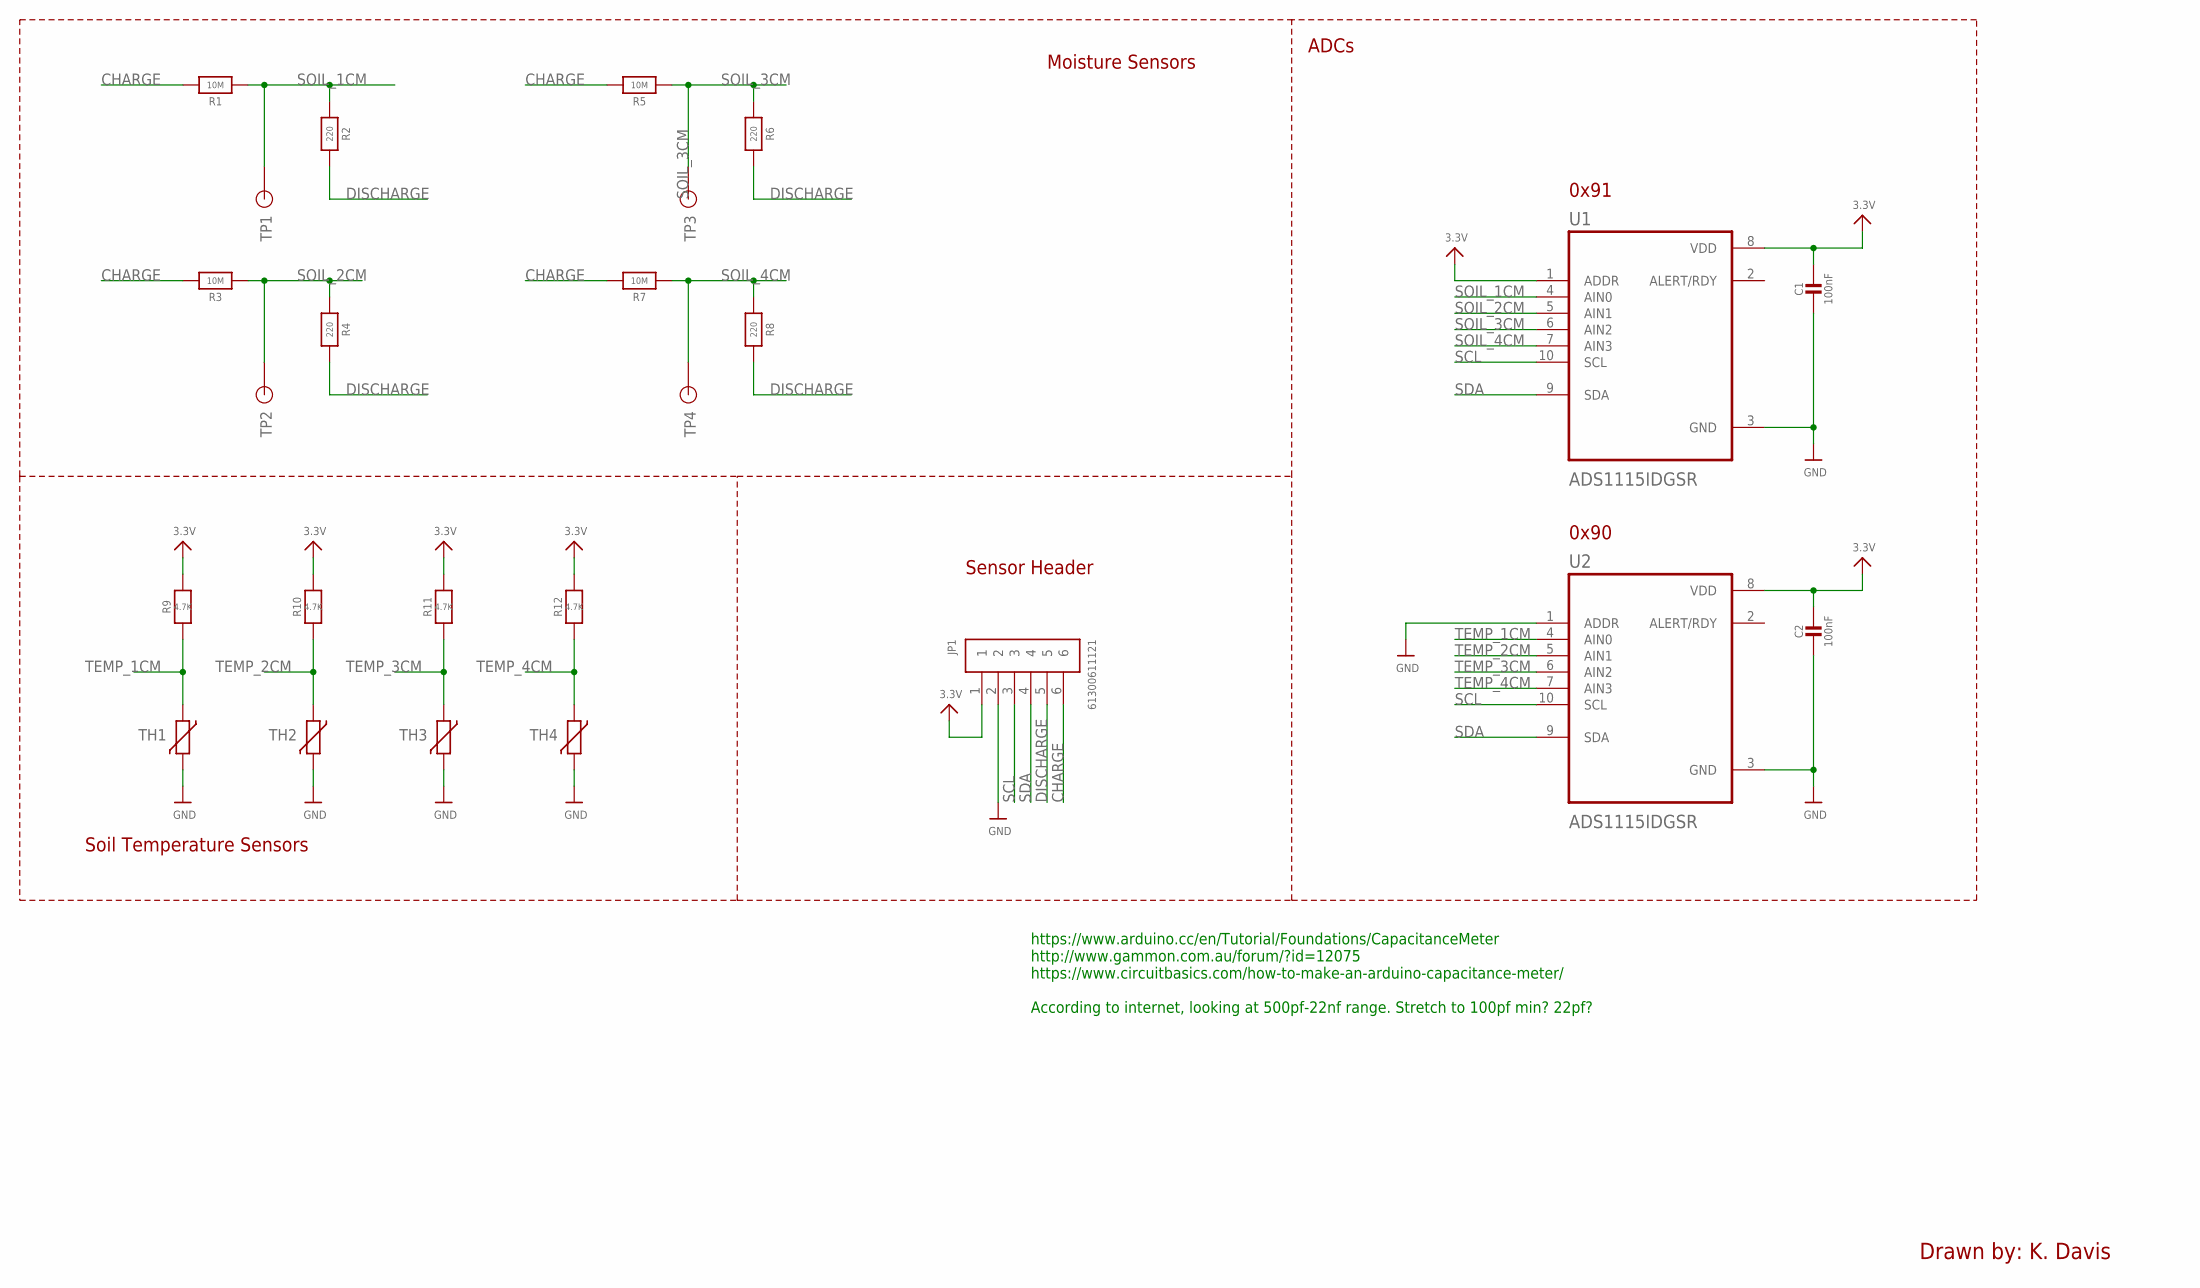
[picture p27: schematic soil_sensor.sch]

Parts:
C1, C2: 100nF; 0805-NO
JP1: 61300611121
R1, R3, R5, R7: 10M; 0805-NO
R2, R4, R6, R8: 220; 0805-NO
R9, R10, R11, R12: 4.7K; 0805-NO
TH1, TH2, TH3, TH4: VARISTORCN0805; CT/CN0805
TP1, TP2, TP3, TP4: TP; TP_50MIL_CIRC
U1, U2: ADS1115IDGSR; SOP50P490X110-10N

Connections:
3.3V: C1.1, C2.1, JP1.1, R9.2, R10.2, R11.2, R12.2, U1.1 (ADDR), U1.8 (VDD), U2.8 (VDD)
CHARGE: JP1.6, R1.2, R3.2, R5.2, R7.2
DISCHARGE: JP1.5, R2.2, R4.2, R6.2, R8.2
GND: C1.2, C2.2, JP1.2, TH1.2, TH2.2, TH3.2, TH4.2, U1.3 (GND), U2.1 (ADDR), U2.3 (GND)
SCL: JP1.3, U1.10 (SCL), U2.10 (SCL)
SDA: JP1.4, U1.9 (SDA), U2.9 (SDA)
SOIL_1CM: R1.1, R2.1, TP1.1, U1.4 (AIN0)
SOIL_2CM: R3.1, R4.1, TP2.1, U1.5 (AIN1)
SOIL_3CM: R5.1, R6.1, TP3.1, U1.6 (AIN2)
SOIL_4CM: R7.1, R8.1, TP4.1, U1.7 (AIN3)
TEMP_1CM: R9.1, TH1.1, U2.4 (AIN0)
TEMP_2CM: R10.1, TH2.1, U2.5 (AIN1)
TEMP_3CM: R11.1, TH3.1, U2.6 (AIN2)
TEMP_4CM: R12.1, TH4.1, U2.7 (AIN3)

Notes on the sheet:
Moisture Sensors
Sensor Header
Drawn by: K. Davis
https://www.arduino.cc/en/Tutorial/Foundations/CapacitanceMeter http://www.gammon.com.au/forum/?id=12075 https://www.circuitbasics.com/how-to-make-an-arduino-capacitance-meter/ According to internet, looking at 500pf-22nf range. Stretch to 100pf min? 22pf?
Soil Temperature Sensors
0x91
0x90
ADCs

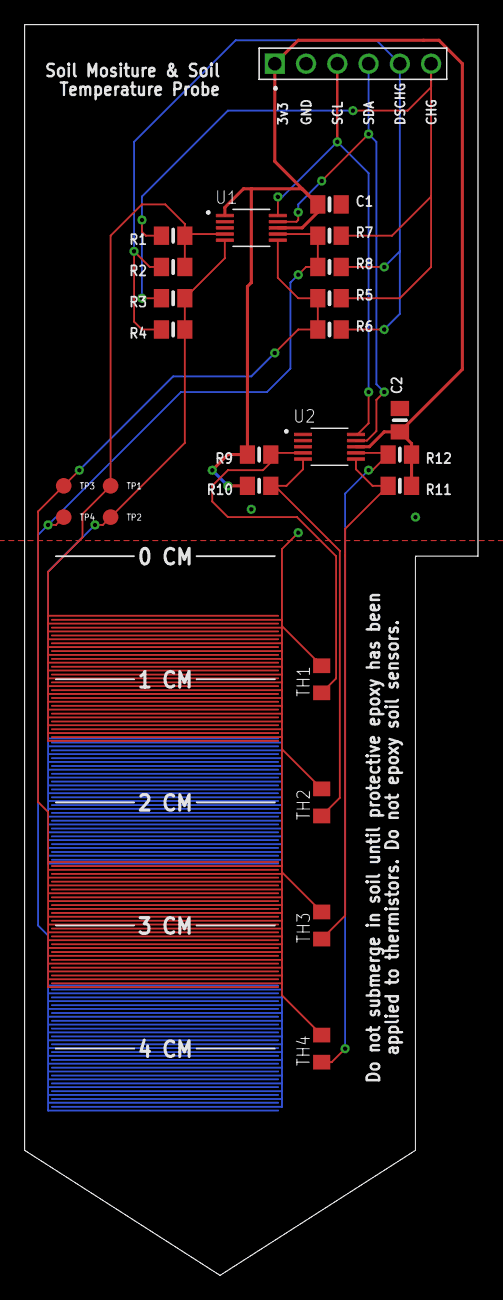
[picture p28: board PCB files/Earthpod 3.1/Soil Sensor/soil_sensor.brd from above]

Board: 2 copper layers, 36.8 x 101.6 mm, 25 parts (0 on the bottom side), 14 nets.

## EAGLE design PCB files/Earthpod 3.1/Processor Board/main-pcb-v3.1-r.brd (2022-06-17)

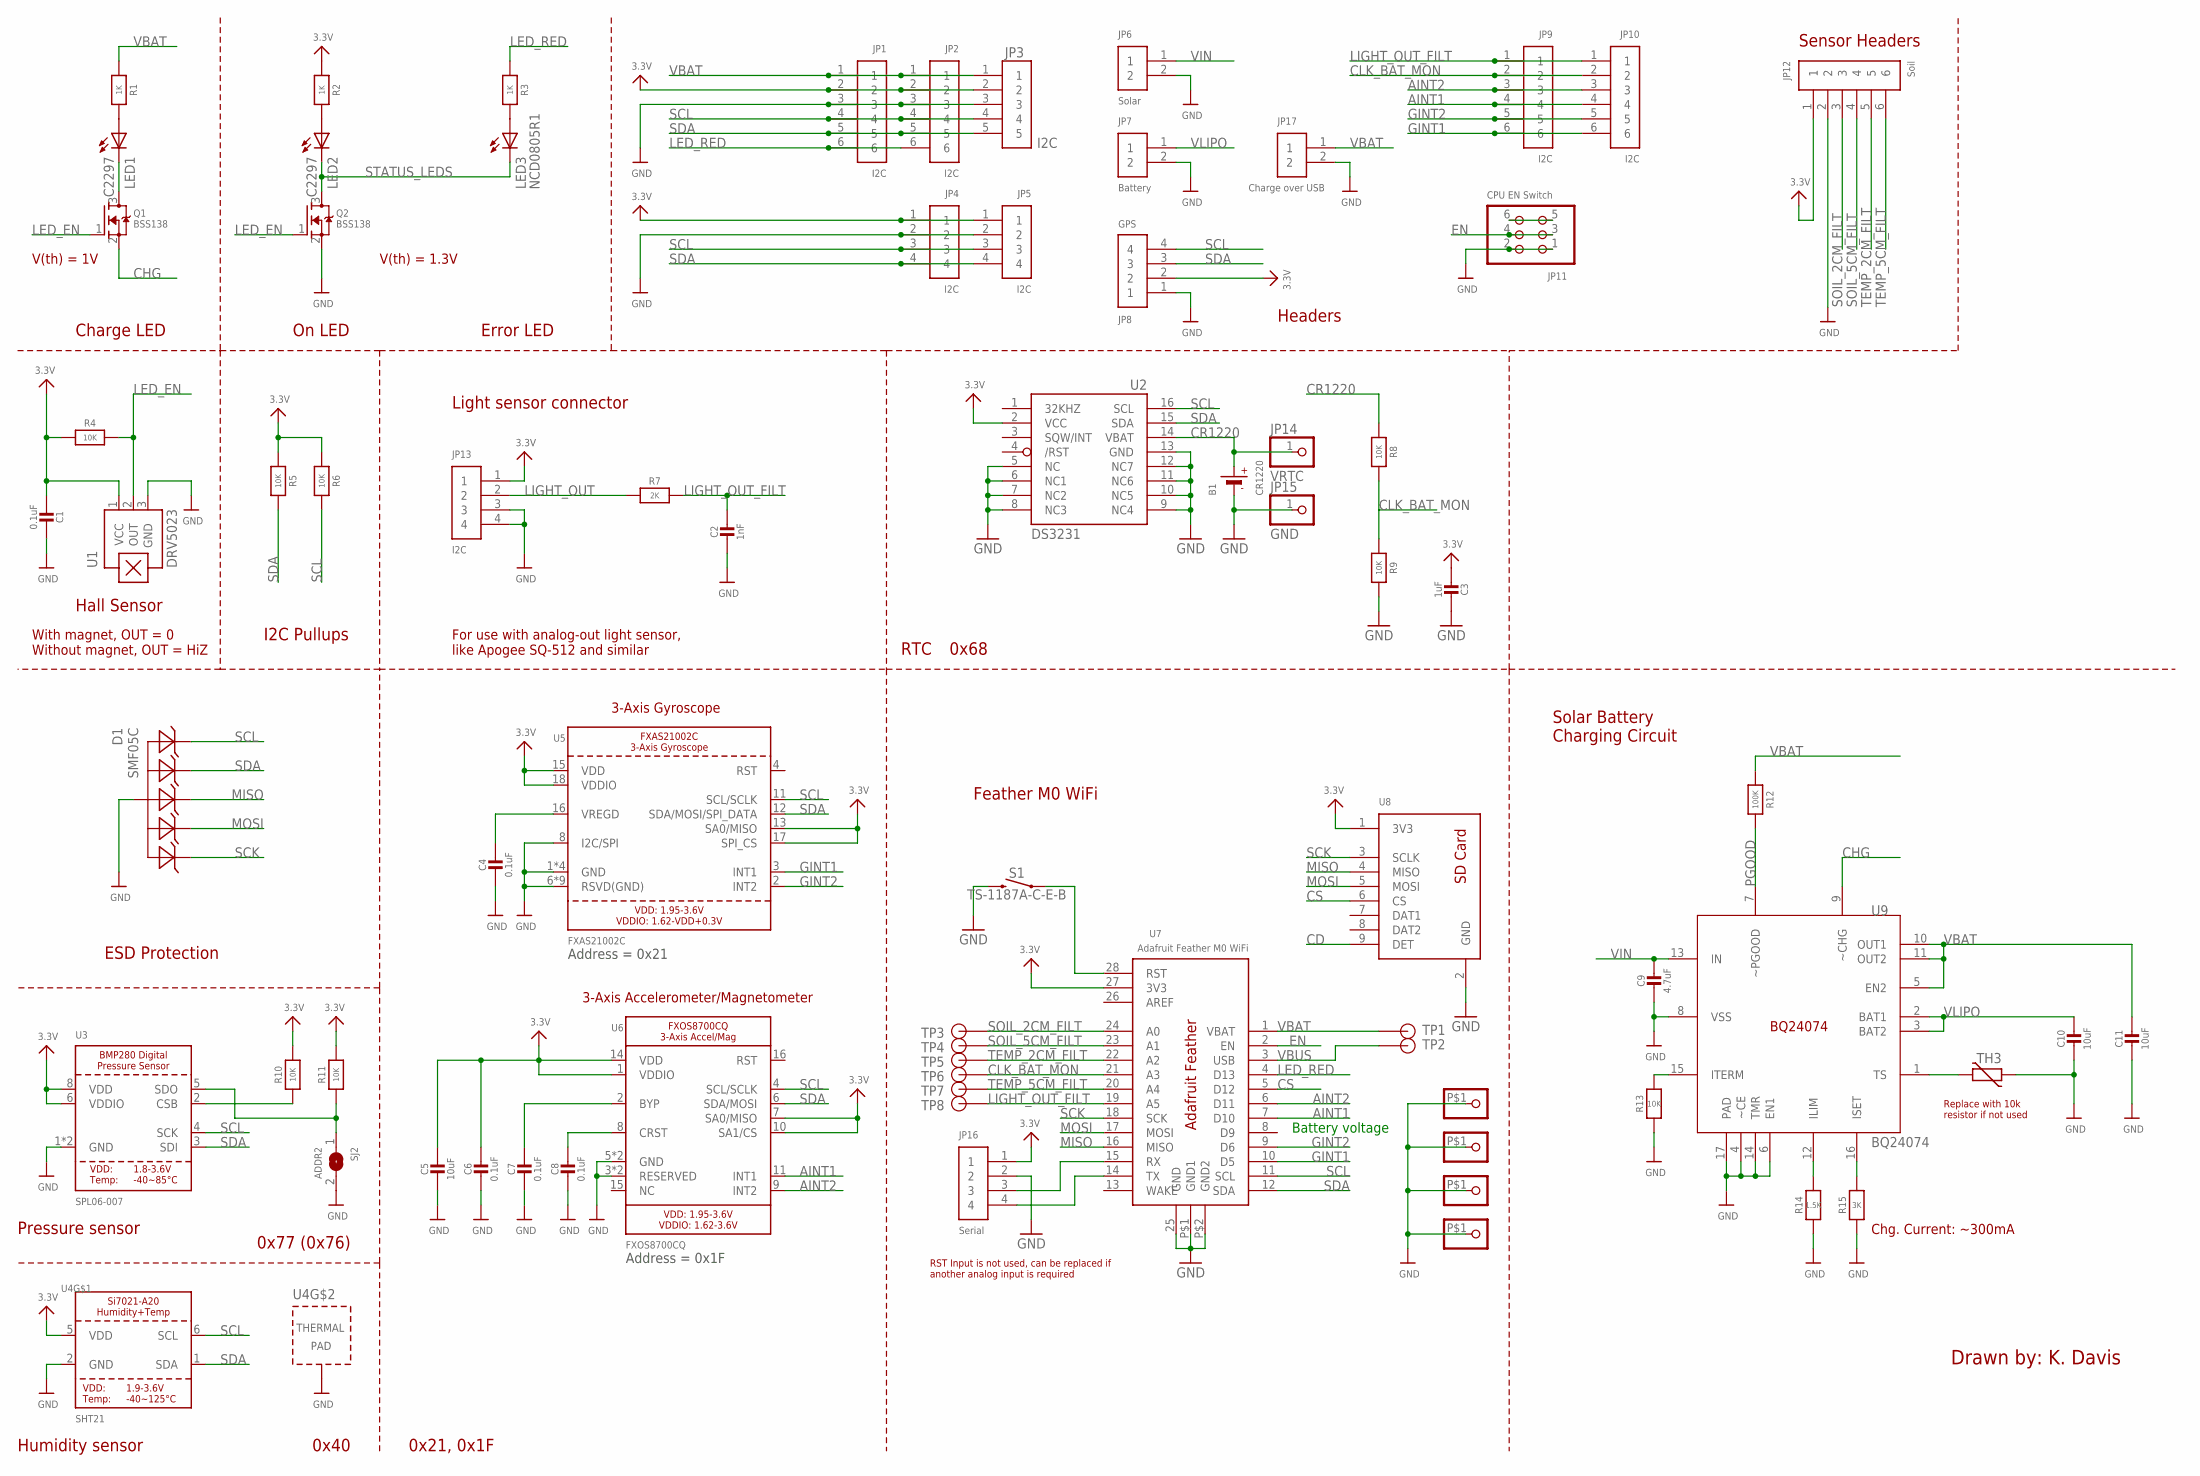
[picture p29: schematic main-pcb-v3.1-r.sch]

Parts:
B1: CR1220; CR1220-2
C1, C4, C6, C7, C8: 0.1uF; 0805-NO
C2: 1nF; 0805-NO
C3: 1uF; 0805-NO
C5, C10, C11: 10uF; 0805-NO
C9: 4.7uF; 0805-NO
D1: SMF05C; SC70-6
JP1, JP2, JP9, JP10: I2C; 61300611121
JP3: I2C; 61300511121
JP4, JP5, JP13: I2C; 61300411121
JP6: Solar; JST-2
JP7: Battery; JST-2
JP8: GPS; JST-4
JP11: CPU EN Switch; 2X03
JP12: Soil; 61300611121
JP14: VRTC; 1X01_ROUND
JP15: GND; 1X01_ROUND
JP16: Serial; 61300411121
JP17: Charge over USB; JST-2
LED1, LED2: C2297; CHIPLED_0805
LED3: NCD0805R1; CHIPLED_0805
Q1, Q2: BSS138; SOT23-WIDE
R1, R2, R3: 1K; 0603-NO
R4, R5, R6, R8, R9, R10, R11: 10K; 0603-NO
R7: 2K; 0603-NO
R12: 100K; 0603-NO
R13: 10K; 0805-NO
R14: 1.5K; 0805-NO
R15: 3K; 0805-NO
S1: TS-1187A-C-E-B; TACTILE_SWITCH_SMD_5.2MM
SJ2: ADDR2; SOLDERJUMPER_ARROW_NOPASTE
TH3: VARISTORCN1206; CT/CN1206
TP1, TP2, TP3, TP4, TP5, TP6, TP7, TP8: TP; TP_50MIL_CIRC
U1: DRV5023; SOT-23
U2: DS3231/SO; SO16W
U3: SPL06-007; BMX280_COMBO
U4: SHT21; DFN6_3X3_SI
U5: FXAS21002C; QFN24_4MM_FREESCALE_7X5
U6: FXOS8700CQ; QFN16_3MM_FREESCALE_5X3
U7: Adafruit Feather M0 WiFi; FEATHER
U8: SDCARD2
U9: BQ24074; VQFN-16_3MM
U$1, U$17, U$19, U$21: MOUNTING

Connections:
3.3V: C1.2, C3.2, C5.1, C6.1, JP1.2, JP2.2, JP3.2, JP4.1, JP5.1, JP8.2, JP12.1, JP13.1, JP16.1, R2.1, R4.1, R5.1, R6.1, R10.2, R11.2, U1.1 (VCC), U2.2 (VCC), U3.6 (VDDIO), U3.8 (VDD), U4.5 (VDD), U5.13 (SA0/MISO), U5.15 (VDD), U5.17 (SPI_CS), U5.18 (VDDIO), U6.1 (VDDIO), U6.7 (SA0/MISO), U6.10 (SA1/CS), U6.14 (VDD), U7.27 (3V3), U8.1 (3V3)
AINT1: JP9.4, JP10.4, U6.11 (INT1), U7.7 (D10)
AINT2: JP9.3, JP10.3, U6.9 (INT2), U7.6 (D11)
CD: U8.9 (DET)
CHG: Q1.2 (S), U9.9 (~CHG)
CLK_BAT_MON: JP9.2, JP10.2, R8.2, R9.1, TP6.1, U7.21 (A3)
CR1220: B1.+, JP14.1, R8.1, U2.14 (VBAT)
CS: U7.5 (D12), U8.6 (CS)
EN: JP11.3, JP11.4, U7.2 (EN)
GINT1: JP9.6, JP10.6, U5.3 (INT1), U7.10 (D5)
GINT2: JP9.5, JP10.5, U5.2 (INT2), U7.9 (D6)
GND: B1.-, C1.1, C2.2, C3.1, C4.2, C5.2, C6.2, C7.2, C8.2, C9.2, C10.2, C11.2, D1.2 (A), JP1.3, JP2.3, JP3.3, JP4.2, JP5.2, JP6.2, JP7.2, JP8.1, JP11.1, JP11.2, JP12.2, JP13.3, JP13.4, JP15.1, JP16.2, JP17.2, Q2.2 (S), R9.2, R13.1, R14.1, R15.1, S1.3 (2), SJ2.2, TH3.2, U1.3 (GND), U2.5 (NC), U2.6 (NC1), U2.7 (NC2), U2.8 (NC3), U2.9 (NC4), U2.10 (NC5), U2.11 (NC6), U2.12 (NC7), U2.13 (GND), U3.1 (GND), U3.7 (GND), U4.2 (GND), U4.PAD (TP), U5.1 (GND), U5.5 (GND), U5.6 (RSVD(GND)), U5.7 (RSVD(GND)), U5.8 (I2C/SPI), U5.9 (RSVD(GND)), U5.10 (RSVD(GND)), U5.14 (GND), U5.19 (GND), U5.20 (RSVD(GND)), U5.21 (RSVD(GND)), U5.22 (RSVD(GND)), U5.23 (RSVD(GND)), U5.24 (RSVD(GND)), U6.3 (RESERVED), U6.5 (GND), U6.12 (GND), U6.13 (RESERVED), U7.25 (GND), U7.P$1 (GND1), U7.P$2 (GND2), U8.2 (GND), U9.4 (~CE), U9.6 (EN1), U9.8 (VSS), U9.14 (TMR), U9.17 (PAD), U$1.P$1, U$17.P$1, U$19.P$1, U$21.P$1
ITERM: R13.2, U9.15 (ITERM)
LED1: LED1.C, Q1.3 (D)
LED_EN: Q1.1 (G), Q2.1 (G), R4.2, U1.2 (OUT)
LED_RED: JP1.6, JP2.6, R3.1, U7.4 (D13)
LIGHT_OUT: JP13.2, R7.1
LIGHT_OUT_FILT: C2.1, JP9.1, JP10.1, R7.2, TP8.1, U7.19 (A5)
MISO: D1.4 (C3), U7.16 (MISO), U8.4 (MISO)
MOSI: D1.5 (C4), U7.17 (MOSI), U8.5 (MOSI)
unnamed: LED2.A, R2.2
unnamed: LED3.A, R3.2
unnamed: R10.1, U3.2 (CSB)
unnamed: R11.1, SJ2.1, U3.5 (SDO)
unnamed: JP16.3, U7.15 (RX)
unnamed: JP11.5, JP11.6
unnamed: JP16.4, U7.14 (TX)
unnamed: TH3.1, U9.1 (TS)
unnamed: S1.1, U7.28 (RST)
unnamed: LED1.A, R1.2
unnamed: R15.2, U9.16 (ISET)
unnamed: R14.2, U9.12 (ILIM)
unnamed: C4.1, U5.16 (VREGD)
unnamed: C7.1, U6.2 (BYP)
unnamed: C8.1, U6.8 (CRST)
PGOOD: R12.2, U9.7 (~PGOOD)
SCK: D1.6 (C5), U7.18 (SCK), U8.3 (SCLK)
SCL: D1.1 (C1), JP1.4, JP2.4, JP3.4, JP4.3, JP5.3, JP8.4, R6.2, U2.16 (SCL), U3.4 (SCK), U4.6 (SCL), U5.11 (SCL/SCLK), U6.4 (SCL/SCLK), U7.11 (SCL)
SDA: D1.3 (C2), JP1.5, JP2.5, JP3.5, JP4.4, JP5.4, JP8.3, R5.2, U2.15 (SDA), U3.3 (SDI), U4.1 (SDA), U5.12 (SDA/MOSI/SPI_DATA), U6.6 (SDA/MOSI), U7.12 (SDA)
SOIL_2CM_FILT: JP12.3, TP3.1, U7.24 (A0)
SOIL_5CM_FILT: JP12.4, TP4.1, U7.23 (A1)
STATUS_LEDS: LED2.C, LED3.C, Q2.3 (D)
TEMP_2CM_FILT: JP12.5, TP5.1, U7.22 (A2)
TEMP_5CM_FILT: JP12.6, TP7.1, U7.20 (A4)
VBAT: C11.1, JP1.1, JP2.1, JP3.1, JP17.1, R1.1, R12.1, TP1.1, U7.1 (VBAT), U9.5 (EN2), U9.10 (OUT1), U9.11 (OUT2)
VBUS: TP2.1, U7.3 (USB)
VIN: C9.1, JP6.1, U9.13 (IN)
VLIPO: C10.1, JP7.1, U9.2 (BAT1), U9.3 (BAT2)

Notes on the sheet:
I2C Pullups
On LED
ESD Protection
Battery voltage
Pressure sensor
Humidity sensor
0x40
0x77 (0x76)
Address = 0x21
Address = 0x1F
3-Axis Accelerometer/Magnetometer
3-Axis Gyroscope
0x21, 0x1F
Chg. Current: ~300mA
Hall Sensor
Charge LED
Solar Battery Charging Circuit
Feather M0 WiFi
With magnet, OUT = 0 Without magnet, OUT = HiZ
V(th) = 1.3V
V(th) = 1V
Drawn by: K. Davis
Replace with 10k resistor if not used
RST Input is not used, can be replaced if another analog input is required
Error LED
Headers
Sensor Headers
Light sensor connector
For use with analog-out light sensor, like Apogee SQ-512 and similar
RTC
0x68

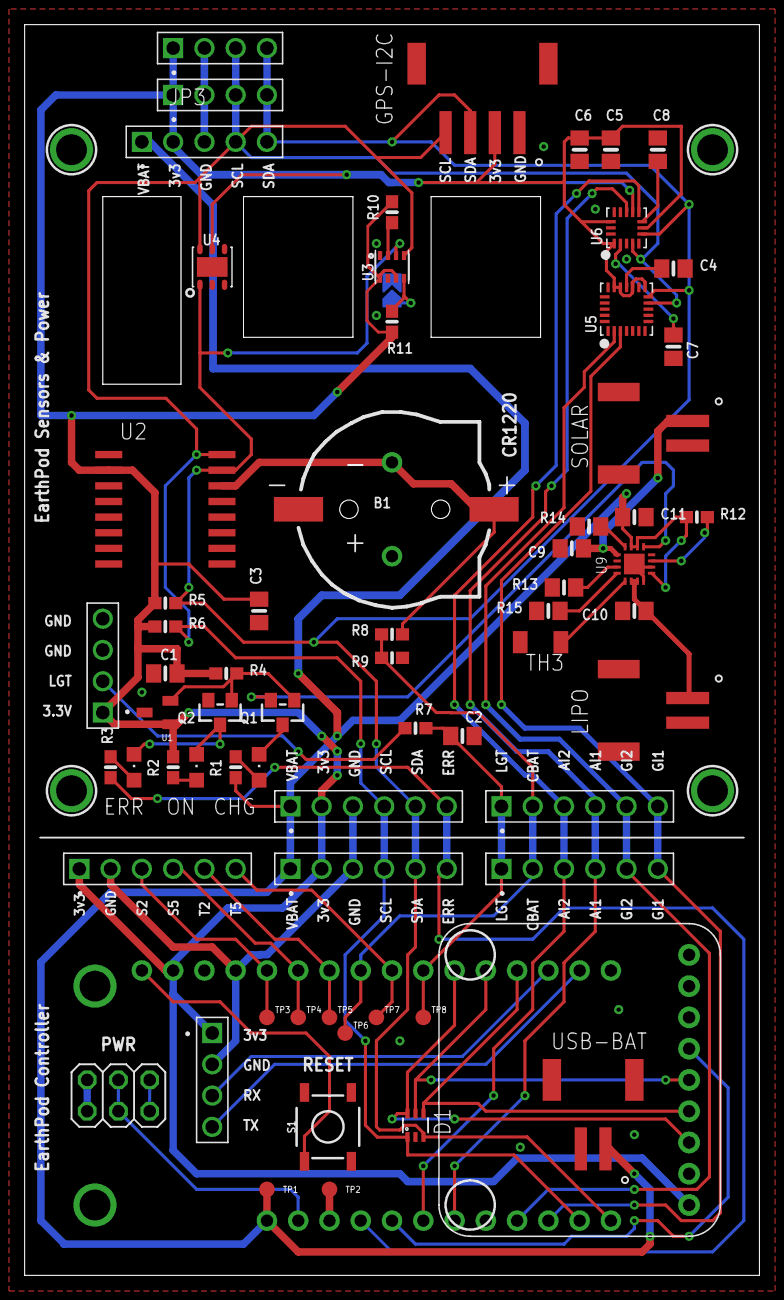
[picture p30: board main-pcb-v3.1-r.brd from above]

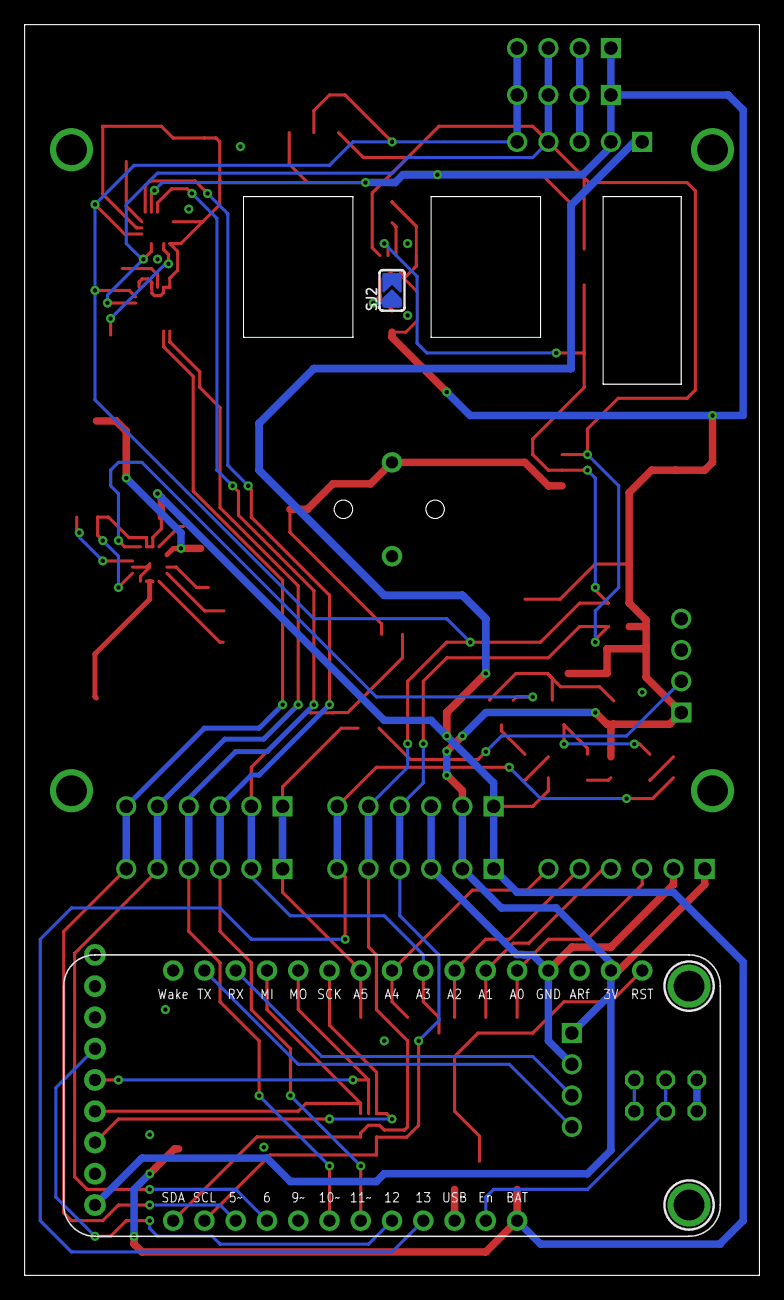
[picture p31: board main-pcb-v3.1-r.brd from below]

Board: 2 copper layers, 59.7 x 101.6 mm, 74 parts (2 on the bottom side), 47 nets.

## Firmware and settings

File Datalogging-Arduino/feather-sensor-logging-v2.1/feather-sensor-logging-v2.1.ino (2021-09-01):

#include "Arduino.h"
#include <Adafruit_SleepyDog.h>
#include "Wire.h"
#include "SPI.h"
#include "SD.h"
#include "Adafruit_Sensor.h"
#include "RTClib.h"                         // RTC
#include "BH1750.h"                         // Light level
#include "SHT2x.h"                          // Humidity and temperature
#include "Adafruit_BMP280.h"                // Air pressure, altitude, and temperature
// SPL06-007 is manually accessed if used   // Air pressure, altitude, and temperature
#include "Adafruit_FXOS8700.h"              // Accelerometer and magnetometer
#include "Adafruit_FXAS21002C.h"            // Gyroscope

// Function prototypes
void blink_led(uint16_t delayTime = 500); // Warning - sensor malfunction, low battery
void enable_led(uint16_t delayTime = 1000); // Logging halted - dead battery, no SD card, no RTC
void log_info(String msg);
void init_SPL06_007(void);
void read_SPL06_007(void);

// Settings
#define LED_ERROR 13
#define SAMPLE_INTERVAL_MS 60000
#define FILE_BASE_NAME "Data"
#define HEADINGS "ID,Year,Month,Day,Hour,Minute,Second,Time Step,Light,Humidity,Pressure,Altitude,Temp (DS3231),Temp (SHT21),Temp (BMP280/SPL06),Accel X,Accel Y,Accel Z,Mag X,Mag Y,Mag Z,Gyro X,Gyro Y,Gyro Z,Battery"
#define VBATPIN A7
#define LOWBATTERY 3.6

// SD card settings
bool sd_present = false;

// V1
//#define CHIP_DETECT 7
//#define CHIP_SELECT 4
//#define LED_WRITE 8

// V2
//#define CHIP_DETECT A4
//#define CHIP_SELECT A5
//#define LED_WRITE -1

// V3
#define CHIP_DETECT -1
#define CHIP_SELECT 12
#define LED_WRITE -1

// Sensor status
bool BH1750_present = true;
bool BMP280_present = true;
bool SPL06_present = false;
bool FXOS8700_present = true;
bool FXAS21002C_present = true;

// Pressure sensor addresses
const int  SPL06_007_I2C = 0x77;    // I2C Address for the temperature sensor
const byte REG_PSR       = 0x00;    // Register Address: Pressure Value (3 bytes)
const byte REG_TMP       = 0x03;    // Register Address: Temperature Value (3 bytes)
const byte REG_PRS_CFG   = 0x06;    // Register Address: Pressure configuration (1 byte)
const byte REG_TMP_CFG   = 0x07;    // Register Address: Temperature configuration (1 byte)
const byte REG_MEAS_CFG  = 0x08;    // Register Address: Measurement configuration (1 byte)
const byte REG_CFG       = 0x09;    // Register Address: Interrupt and FIFO configuration (1 byte)
const byte REG_ID        = 0x0D;    // Register Address: Device ID (1 byte)
const byte REG_COEF      = 0x10;    // Register Address: Calibration coefficients (18 bytes)

// Pressure sensor calibration coefficients
int16_t c0, c1;
int32_t c00, c10;
int16_t c01, c11, c20, c21, c30;

// Pressure sensor scaling factors
float kt;
float kp;
static float scale_factor(int oversampling_rate){
    float k;
    switch (oversampling_rate) {
        case 1:
            k = 524288.0f;
        break;

        case 2:
            k = 1572864.0f;
        break;

        case 4:
            k = 3670016.0f;
        break;

        case 8:
            k = 7864320.0f;
        break;

        case 16:
            k = 253952.0f;
        break;

        case 32:
            k = 516096.0f;
        break;

        case 64:
            k = 1040384.0f;
        break;

        case 128:
            k = 2088960.0f;
        break;
    }
    return k;
}
 
// Tropospheric properties (0-11km) for standard atmosphere
const float T1 = 15.0f + 273.15f;       // temperature at base height in Kelvin
const float a  = -6.5f / 1000.0f;       // temperature gradient in degrees per metre
const float g  = 9.80665f;              // gravity constant in m/s/s
const float R  = 287.05f;               // ideal gas constant in J/kg/K
const float msl_pressure = 101325.0f;   // in Pa

// Light sensor results
float lux = 0;

// Pressure sensor results
float bmp_spl_temperature = 25;
float bmp_spl_pressure = 101325;
float bmp_spl_altitude = 0;

// File variables
const uint8_t BASE_NAME_SIZE = sizeof(FILE_BASE_NAME) - 1;
char filename[13] = FILE_BASE_NAME "00.csv";
char logfilename[8] = "log.txt";

// Measurement time and number
double t0 = 0;
double counter = 0;

// Battery voltage variable
float measuredvbat;

// Create sensor objects
RTC_DS3231 rtc;
BH1750 lightMeter;
Adafruit_BMP280 bmp;
Adafruit_FXOS8700 accelmag = Adafruit_FXOS8700(0x8700A, 0x8700B);
Adafruit_FXAS21002C gyro = Adafruit_FXAS21002C(0x0021002C);

void setup() {
  if (LED_ERROR >= 0) {
    pinMode(LED_ERROR, OUTPUT);
    digitalWrite(LED_ERROR, LOW);
  }
  
  if (LED_WRITE >= 0) {
    pinMode(LED_WRITE, OUTPUT);
    digitalWrite(LED_WRITE, LOW);
  }
  
  Wire.begin();
  Serial.begin(9600);
  delay(2000);  
  
  // Check the Battery Voltage ////////////////////////////////////////////////////////////
  measuredvbat = analogRead(VBATPIN);
  measuredvbat *= 2;    // we divided by 2, so multiply back
  measuredvbat *= 3.3;  // Multiply by 3.3V, our reference voltage
  measuredvbat /= 1024; // convert to voltage
  Serial.print("Battery Voltage: " );
  Serial.println(measuredvbat);

  if (measuredvbat <= LOWBATTERY) {
    log_info("Low battery, halting");
    Serial.flush();
    while(1){enable_led();}
  }

  // Initialize the SD card ///////////////////////////////////////////////////////////////  
  if (CHIP_DETECT >= 0) {
    pinMode(CHIP_DETECT, INPUT);
    if (!digitalRead(CHIP_DETECT)) {
      sd_present = false;
      log_info("SD card not present");
    }
  }

  // Try to initialize even if card is not detected
  if (!SD.begin(CHIP_SELECT)) {
    sd_present = false;
    if (LED_ERROR >= 0) {digitalWrite(LED_ERROR, HIGH);}
    log_info("SD card failed");
  } else {
    sd_present = true;
    log_info("------");
    log_info("SD card initialized");
  }

  // Initialize sensors ///////////////////////////////////////////////////////////////////
  if (!rtc.begin()) {
    log_info("RTC not found, halting");
    Serial.flush();
    while(1){enable_led();}
  }

  if (rtc.lostPower()) {
    log_info("RTC lost power, setting time");
    rtc.adjust(DateTime(F(__DATE__), F(__TIME__)));
  }

  char dt[16];
  char tm[16];
  DateTime now = rtc.now();
  sprintf(dt, "%02d/%02d/%02d", now.year(),now.month(),now.day());
  sprintf(tm, "%02d:%02d:%02d", now.hour(),now.minute(),now.second());
  log_info(dt);
  log_info(tm);

  if (lightMeter.begin()) {
    log_info("BH1750 connected");
  } else {
    BH1750_present = false;
    log_info("Light sensor not found");
  }

  if (!bmp.begin(0x76)) {
    BMP280_present = false;
    SPL06_present = true;
    init_SPL06_007();
  } else {
    /* Default settings from datasheet. */
    bmp.setSampling(Adafruit_BMP280::MODE_NORMAL,     /* Operating Mode. */
                    Adafruit_BMP280::SAMPLING_X2,     /* Temp. oversampling */
                    Adafruit_BMP280::SAMPLING_X16,    /* Pressure oversampling */
                    Adafruit_BMP280::FILTER_X16,      /* Filtering. */
                    Adafruit_BMP280::STANDBY_MS_500); /* Standby time. */
  }

  if (BMP280_present) {
    log_info("BMP280 connected");
  } else if (SPL06_present) {
    log_info("SPL06_007 connected");
  } else {
    log_info("Pressure sensor not found");
  }

  if (accelmag.begin(ACCEL_RANGE_4G)) {
    log_info("FXOS8700 connected");
  } else {
    FXOS8700_present = false;
    log_info("FXOS8700 not found");
  }

  if (gyro.begin()) {
    log_info("FXAS21002C connected");
  } else {
    FXAS21002C_present = false;
    log_info("FXAS21002C not found");
  }

  // Create sensor data file //////////////////////////////////////////////////////////////
  if (sd_present) {
    // Find an unused file name.
    if (BASE_NAME_SIZE > 6) {
      log_info("FILE_BASE_NAME too long");
    }
    while (SD.exists(filename)) {
      if (filename[BASE_NAME_SIZE + 1] != '9') {
        filename[BASE_NAME_SIZE + 1]++;
      } else if (filename[BASE_NAME_SIZE] != '9') {
        filename[BASE_NAME_SIZE + 1] = '0';
        filename[BASE_NAME_SIZE]++;
      } else {
        log_info("Can't create file name");
        sd_present = false;
      }
    }
  }
  
  if (sd_present) {
    File file = SD.open(filename, FILE_WRITE);  
    file.println(HEADINGS);
    file.close();
    log_info("Sensor data file created");
    log_info(filename);
  }

  // Get start time ///////////////////////////////////////////////////////////////////////
  t0 = millis();
  int wdtCountdown = Watchdog.enable(2000);
}

void loop() {  
  Watchdog.reset();
  Serial.println("===================");
  
  // RTC
  char dt[16];
  char tm[16];
  DateTime now = rtc.now();
  sprintf(dt, "%02d/%02d/%02d", now.year(),now.month(),now.day());
  sprintf(tm, "%02d:%02d:%02d", now.hour(),now.minute(),now.second());
  
  Serial.print("RTC: ");
  Serial.print(dt);
  Serial.print(' ');
  Serial.print(tm);
  Serial.println();

  // Time step
  double ts = (millis() - t0)/1000.0;
  t0 = millis();
  Serial.print("Time Step: ");
  Serial.println(String(ts));

  // Light level
  if (BH1750_present) {
    lux = lightMeter.readLightLevel();
    Serial.print("Light: ");
    Serial.println(lux);
  }

  // Humidity
  float rh = SHT2x.GetHumidity();
  Serial.print("Humidity(%RH): ");
  Serial.println(rh);

  // Pressure and altitude
  if (BMP280_present) {
    bmp_spl_temperature = bmp.readTemperature();
    bmp_spl_pressure = bmp.readPressure();
    bmp_spl_altitude = bmp.readAltitude(1013.25);
  } else if (SPL06_present) {
    read_SPL06_007();
  }

  // Temperature
  float temp_ds3231 = rtc.getTemperature();
  float temp_sht21 = SHT2x.GetTemperature();  
  Serial.println("Temperature(C)");
  Serial.print("     DS3231: ");
  Serial.println(temp_ds3231);
  Serial.print("     SHT21: ");
  Serial.println(temp_sht21);

  if (BMP280_present || SPL06_present) {
    Serial.print("     BMP280/SPL06: ");
    Serial.println(bmp_spl_temperature);    
    Serial.print("Pressure: ");
    Serial.println(bmp_spl_pressure, DEC);
    Serial.print("Altitude: ");
    Serial.println(bmp_spl_altitude, DEC);
  }

  // Battery Voltage
  measuredvbat = analogRead(VBATPIN);
  measuredvbat *= 2;    // we divided by 2, so multiply back
  measuredvbat *= 3.3;  // Multiply by 3.3V, our reference voltage
  measuredvbat /= 1024; // convert to voltage
  Serial.print("Battery Voltage: " );
  Serial.println(measuredvbat);
  
  // SD Card
  Serial.print("SD Card Status: " );
  Serial.println(sd_present);

  if(sd_present){
    // Open file
    if (LED_WRITE >= 0) {digitalWrite(LED_WRITE, HIGH);}
    File file = SD.open(filename, FILE_WRITE);
    file.seek(EOF);
    Serial.print("Filename: " );
    Serial.println(filename);

    // Trial number
    file.print(String(counter));
    file.print(",");

    // RTC
    file.print(String(now.year()));
    file.print(",");
    file.print(String(now.month()));
    file.print(",");
    file.print(String(now.day()));
    file.print(",");
    file.print(String(now.hour()));
    file.print(",");
    file.print(String(now.minute()));
    file.print(",");
    file.print(String(now.second()));
    file.print(",");

    // Time Step
    file.print(String(ts));
    file.print(",");

    // Light Level
    if (BH1750_present) {
      file.print(String(lux));
      file.print(",");
    } else {
      file.print(",");
    }    

    // Humidity
    file.print(String(rh));
    file.print(",");

    // Pressure and Altitude
    if (BMP280_present || SPL06_present) {
      file.print(String(bmp_spl_pressure));
      file.print(",");
      file.print(String(bmp_spl_altitude));
      file.print(",");
    } else {
      file.print(",,");
    }

    // Temperature
    file.print(String(temp_ds3231));
    file.print(",");
    file.print(String(temp_sht21));
    file.print(",");

    if (BMP280_present || SPL06_present) {
      file.print(String(bmp_spl_temperature));
      file.print(",");
    } else {
      file.print(",");
    }

    // Accelerometer/Magnetometer
    if (FXOS8700_present) {
      sensors_event_t aevent, mevent;
      accelmag.getEvent(&aevent, &mevent);
      file.print(String(aevent.acceleration.x));
      file.print(",");
      file.print(String(aevent.acceleration.y));
      file.print(",");
      file.print(String(aevent.acceleration.z));
      file.print(",");

      file.print(String(mevent.magnetic.x));
      file.print(",");
      file.print(String(mevent.magnetic.y));
      file.print(",");
      file.print(String(mevent.magnetic.z));
      file.print(",");
    } else {
      file.print(",,,,,,");
    }
  
    // Gyro
    if (FXAS21002C_present) {
      sensors_event_t event;
      gyro.getEvent(&event);
      file.print(String(event.gyro.x));
      file.print(",");
      file.print(String(event.gyro.y));
      file.print(",");
      file.print(String(event.gyro.z));
      file.print(",");
    } else {
      file.print(",,,");
    }

    // Battery Voltage
    file.print(String(measuredvbat));
    
    // Close file
    file.println();
    file.close();
    if (LED_WRITE >= 0) {digitalWrite(LED_WRITE, LOW);}
  }

  Serial.println();
  counter++;

  while((millis() - t0) < SAMPLE_INTERVAL_MS){
    Watchdog.reset();
    
    if (!sd_present) {
      enable_led(); // If the SD card is missing or failed to initialize, turn the status led on
    } else if (measuredvbat <= LOWBATTERY) {
      blink_led(); // If the battery is low, make the status led blink
    } else if ((!SPL06_present) && (!BMP280_present)) {
      blink_led(); // If the pressure sensor is missing or failed to initialize, make the status led blink
    } else {
      delay(1000);
    }

    if (Serial.available() > 0) {
      char receivedChar = Serial.read();
      if (receivedChar == 'c') {
        log_info("c -> Clock reset requested, setting time");
        rtc.adjust(DateTime(F(__DATE__), F(__TIME__)));
  
        char dt[16];
        char tm[16];
        DateTime now = rtc.now();
        sprintf(dt, "%02d/%02d/%02d", now.year(),now.month(),now.day());
        sprintf(tm, "%02d:%02d:%02d", now.hour(),now.minute(),now.second());
        log_info(dt);
        log_info(tm);
      } else if (receivedChar == 's') {
        log_info("s -> Manual sample requested");
        break; // Skip waiting for sample interval
      } else if (receivedChar == 'r') {
        log_info("r -> Reset requested");
        Serial.flush();
        while(1){enable_led();} // Allow watchdog timer to expire
      }
    }
  }
}

void blink_led(uint16_t delayTime) {
  if (LED_ERROR >= 0) {
    digitalWrite(LED_ERROR, HIGH); // turn the LED on
    delay(delayTime);
    digitalWrite(LED_ERROR, LOW);  // turn the LED off
    delay(delayTime);
  } else {
    delay(delayTime * 2);
  }
}

void enable_led(uint16_t delayTime) {
  if (LED_ERROR >= 0) {
    digitalWrite(LED_ERROR, HIGH); // turn the LED on
    delay(delayTime);
  } else {
    delay(delayTime);
  }
}

void log_info(String msg) {
  Serial.println(msg);
  
  if (sd_present) {
    if (LED_WRITE >= 0) {digitalWrite(LED_WRITE, HIGH);}
    File logfile = SD.open(logfilename, FILE_WRITE);
    logfile.seek(EOF);
    logfile.println(msg);
    logfile.close();
    if (LED_WRITE >= 0) {digitalWrite(LED_WRITE, LOW);}
  }
}

void init_SPL06_007() {
  // Try to start pressure sensor
  Serial.println("Initializing pressure sensor...");
  uint8_t tries = 5;
  while(tries > 0){
      // Check chip ID
      Wire.beginTransmission (SPL06_007_I2C);
      Wire.write             (REG_ID);
      Wire.endTransmission   ();
      Wire.requestFrom       (SPL06_007_I2C, 1);
      byte device_id = Wire.read();
      Serial.print("Device ID: ");
      Serial.println(device_id, BIN);
      
      if (device_id == 0x10) {
          // Check if sensors are ready
          Wire.beginTransmission (SPL06_007_I2C);
          Wire.write             (REG_MEAS_CFG);
          Wire.endTransmission   ();
          Wire.requestFrom       (SPL06_007_I2C, 1);        
          byte meas_cfg = Wire.read();
          Serial.print("Measurement configuration: ");       
          Serial.println(meas_cfg, BIN);
          
          if (meas_cfg & (1 << 7) && meas_cfg & (1 << 6)) {
              break;
          }
      }

      tries = tries - 1;
      delay(1000);
  }

  // If initialization failed
  if (!tries) {
      log_info("Could not initialize pressure sensor");
      SPL06_present = false;
  }

  if (SPL06_present) {
    // Read calibration coefficients
    Wire.beginTransmission (SPL06_007_I2C);
    Wire.write             (REG_COEF);
    Wire.endTransmission   ();
    Wire.requestFrom       (SPL06_007_I2C, 18);
  
    byte coef_bytes[18];
    for(uint8_t i = 0; i < 18; i++){
      coef_bytes[i] = Wire.read();
    }
  
    c0 = (uint16_t)coef_bytes[0] << 4 | (uint16_t)coef_bytes[1] >> 4;
    c0 = (c0 & 1 << 11) ? (0xf000 | c0) : c0;
  
    c1 = (uint16_t)(coef_bytes[1] & 0x0f) << 8 | (uint16_t)coef_bytes[2];
    c1 = (c1 & 1 << 11) ? (0xf000 | c1) : c1;
  
    c00 = (uint32_t)coef_bytes[3] << 12 | (uint32_t)coef_bytes[4] << 4 | (uint16_t)coef_bytes[5] >> 4;
    c00 = (c00 & 1 << 19) ? (0xfff00000 | c00) : c00;
  
    c10 = (uint32_t)(coef_bytes[5] & 0x0f) << 16 | (uint32_t)coef_bytes[6] << 8 | (uint32_t)coef_bytes[7];
    c10 = (c10 & 1 << 19) ? (0xfff00000 | c10) : c10;
  
    c01 = (uint16_t)coef_bytes[8] << 8 | coef_bytes[9];
    c11 = (uint16_t)coef_bytes[10] << 8 | coef_bytes[11];
    c20 = (uint16_t)coef_bytes[12] << 8 | coef_bytes[13];
    c21 = (uint16_t)coef_bytes[14] << 8 | coef_bytes[15];
    c30 = (uint16_t)coef_bytes[16] << 8 | coef_bytes[17];
    
    Serial.println("----------");
    Serial.println("Calibration coeffecients: ");
    Serial.print("C0: ");       
    Serial.println(c0, DEC);
    Serial.print("C1: ");       
    Serial.println(c1, DEC);
    Serial.print("C00: ");       
    Serial.println(c00, DEC);
    Serial.print("C10: ");       
    Serial.println(c10, DEC);
    Serial.print("C01: ");       
    Serial.println(c01, DEC);
    Serial.print("C11: ");       
    Serial.println(c11, DEC);
    Serial.print("C20: ");       
    Serial.println(c20, DEC);
    Serial.print("C21: ");       
    Serial.println(c21, DEC);
    Serial.print("C30: ");       
    Serial.println(c30, DEC);  
    Serial.println("----------");
  
    // Write configuration settings
  
    // configuration of pressure measurement rate (PM_RATE) and resolution (PM_PRC)
    //
    // bit[7]: reserved
    //
    // PM_RATE[6:4]    : 0 | 1 | 2 | 3 | 4  | 5  | 6  | 7
    // measurement rate: 1 | 2 | 4 | 8 | 16 | 32 | 64 | 128
    // note: applicable for measurements in background mode only
    //
    // PM_PRC[3:0]         : 0      | 1   | 2   | 3    | 4    | 5    | 6     | 7
    // oversampling (times): single | 2   | 4   | 8    | 16   | 32   | 64    | 128
    // measurement time(ms): 3.6    | 5.2 | 8.4 | 14.8 | 27.6 | 53.2 | 104.4 | 206.8
    // precision(PaRMS)    : 5.0    |     | 2.5 |      | 1.2  | 0.9  | 0.5   |
    // note: use in combination with a bit shift when the oversampling rate is > 8 times. see CFG_REG(0x19) register
    Wire.beginTransmission (SPL06_007_I2C);
    Wire.write             (REG_PRS_CFG);
    Wire.write             (0 << 4 | 4);
    Wire.endTransmission   ();
  
    // configuration of temperature measurment rate (TMP_RATE) and resolution (TMP_PRC)
    //
    // temperature measurement: internal sensor (in ASIC) | external sensor (in pressure sensor MEMS element)
    // TMP_EXT[7]             : 0                         | 1
    // note: it is highly recommended to use the same temperature sensor as the source of the calibration coefficients wihch can be read from reg 0x28
    //
    // TMP_RATE[6:4]   : 0 | 1 | 2 | 3 | 4  | 5  | 6  | 7
    // measurement rate: 1 | 2 | 4 | 8 | 16 | 32 | 64 | 128
    // note: applicable for measurements in background mode only
    //
    // bit[3]: reserved
    //
    // TMP_PRC[2:0]        : 0      | 1 | 2 | 3 | 4  | 5  | 6  | 7
    // oversampling (times): single | 2 | 4 | 8 | 16 | 32 | 64 | 128
    // note: single(default) measurement time 3.6ms, other settings are optional, and may not be relevant
    // note: use in combination with a bit shift when the oversampling rate is > 8 times. see CFG_REG(0x19) register
    Wire.beginTransmission (SPL06_007_I2C);
    Wire.write             (REG_TMP_CFG);
    Wire.write             (1 << 7 | 0 << 4 | 3);
    Wire.endTransmission   ();
  
    // sensor operating mode
    // measurement mode: stop meas |  command mode(single) |    na |            background mode(continuous) |
    // measurement type:      idle | pres meas | temp meas |    na | pres meas | temp meas | pres&temp meas |
    // MEAS_CTRL[2:0]  :         0 |         1 |         2 | 3 | 4 |         5 |         6 |              7 |
    Wire.beginTransmission (SPL06_007_I2C);
    Wire.write             (REG_MEAS_CFG);
    Wire.write             (7);
    Wire.endTransmission   ();  
  
    // diasble all interrupts and FIFO
    //
    // bit7: interrupt(on SDO pin) active level
    //       0-active low  1-active hight
    //
    // bit6: set to '1' for FIFO full interrupt
    // bit5: set to '1' for pressure measurement ready interrupt
    // bit4: set to '1' for temperature measurement ready interrupt
    //
    // note: bit3 must be set to '1' when the temperature oversampling rate is > 8 times
    // note: bit2 must be set to '1' when the pressure oversampling rate is > 8 times
    //
    // bit1: set to '1' for FIFO enable
    //
    // bit0: set to '0' for 4-wire interface
    //       set to '1' for 3-wire interface
    Wire.beginTransmission (SPL06_007_I2C);
    Wire.write             (REG_CFG);
    Wire.write             (1 << 2);
    Wire.endTransmission   ();
    
    // compensation scale factors
    // oversampling rate  : single | 2       | 4       | 8       | 16     | 32     | 64      | 128
    // scale factor(KP/KT): 524288 | 1572864 | 3670016 | 7864320 | 253952 | 516096 | 1040384 | 2088960  
    kp = scale_factor(16);
    kt = scale_factor(8);
  }
}
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

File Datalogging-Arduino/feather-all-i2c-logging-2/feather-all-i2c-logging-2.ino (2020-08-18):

#include "Wire.h"
#include "SPI.h"
#include "SdFat.h"
#include "Adafruit_Sensor.h"
#include "RTClib.h"
// #include "Adafruit_FXAS21002C.h"
// #include "Adafruit_FXOS8700.h"
#include "Adafruit_BME280.h"
// #include "Adafruit_TCS34725.h"
#include "Adafruit_SI1145.h"

#define CHIP_SELECT 4
#define FILE_BASE_NAME "Data"
#define error(msg) sd.errorHalt(F(msg))

#define SEALEVELPRESSURE_HPA (1013.25)
// #define HEADINGS "year,month,day,hour,minute,second,gyro x,gyro y,gyro z,accel x, accel y, accel z,mag x, mag y, mag z,temperature,pressure,altitude,humidity,r,g,b,vis,ir,uv"
#define HEADINGS "year,month,day,hour,minute,second,temperature,pressure,altitude,humidity,vis,ir,uv"
#define SAMPLE_INTERVAL_MS 5000

SdFat sd;
SdFile file;
RTC_DS3231 rtc;
// Adafruit_FXAS21002C gyro = Adafruit_FXAS21002C(0x0021002C);
// Adafruit_FXOS8700 accelmag = Adafruit_FXOS8700(0x8700A, 0x8700B);
Adafruit_BME280 bme;
// Adafruit_TCS34725 tcs = Adafruit_TCS34725(TCS34725_INTEGRATIONTIME_700MS, TCS34725_GAIN_1X);
Adafruit_SI1145 uv = Adafruit_SI1145();

const uint8_t BASE_NAME_SIZE = sizeof(FILE_BASE_NAME) - 1;
char fileName[13] = FILE_BASE_NAME "00.csv";

void setup() {  
  Serial.begin(9600);
  
  while (!Serial) {
    delay(1);
  }

  // Initialize the SD card ///////////////////////////////////////////////////////////////
  // Initialize at the highest speed supported by the board that is
  // not over 50 MHz. Try a lower speed if SPI errors occur.
  if (!sd.begin(CHIP_SELECT, SD_SCK_MHZ(50))) {
    sd.initErrorHalt();
  }

  // Find an unused file name.
  if (BASE_NAME_SIZE > 6) {
    error("FILE_BASE_NAME too long");
  }
  while (sd.exists(fileName)) {
    if (fileName[BASE_NAME_SIZE + 1] != '9') {
      fileName[BASE_NAME_SIZE + 1]++;
    } else if (fileName[BASE_NAME_SIZE] != '9') {
      fileName[BASE_NAME_SIZE + 1] = '0';
      fileName[BASE_NAME_SIZE]++;
    } else {
      error("Can't create file name");
    }
  }
  if (!file.open(fileName, O_WRONLY | O_CREAT | O_EXCL)) {error("open");}

  Serial.print(F("Logging to: "));
  Serial.println(fileName);

  // Initialize sensors ///////////////////////////////////////////////////////////////////
  if (! rtc.begin()) {
    Serial.println("No RTC found");
    Serial.flush();
    abort();
  }

  if (rtc.lostPower()) {
    Serial.println("RTC lost power, setting time");
    rtc.adjust(DateTime(F(__DATE__), F(__TIME__)));
  }

  /*if (!gyro.begin()) {
    Serial.println("No FXAS21002C found");
    while(1);
  }

  if (!accelmag.begin(ACCEL_RANGE_4G)) {
    Serial.println("No FXOS8700 found");
    while(1);
  }*/

  if (!bme.begin()) {
    Serial.println("No BME280 found");
    Serial.print("SensorID was: 0x"); Serial.println(bme.sensorID(),16);
    while(1);
  }

  /*if (!tcs.begin()) {
    Serial.println("No TCS34725 found");
    while(1);
  }*/

  if (!uv.begin()) {
    Serial.println("No Si1145 found");
    while(1);
  }
  
  file.println(HEADINGS);
  if (!file.close()) error("close");
}

void loop() {
  if (!file.open(fileName, O_CREAT | O_APPEND | O_WRITE)) error("open");

  Serial.println("===================");
  
  // RTC
  DateTime now = rtc.now();
  Serial.print("RTC  ");
  Serial.print(now.year(), DEC);
  Serial.print('/');
  Serial.print(now.month(), DEC);
  Serial.print('/');
  Serial.print(now.day(), DEC);
  Serial.print(" ");
  Serial.print(now.hour(), DEC);
  Serial.print(':');
  Serial.print(now.minute(), DEC);
  Serial.print(':');
  Serial.print(now.second(), DEC);
  Serial.println();
  
  // RTC
  file.print(String(now.year()));
  file.print(",");
  file.print(String(now.month()));
  file.print(",");
  file.print(String(now.day()));
  file.print(",");
  file.print(String(now.hour()));
  file.print(",");
  file.print(String(now.minute()));
  file.print(",");
  file.print(String(now.second()));
  file.print(",");

  // Gyro
  /*sensors_event_t event;
  gyro.getEvent(&event);
  file.print(String(event.gyro.x));
  file.print(",");
  file.print(String(event.gyro.y));
  file.print(",");
  file.print(String(event.gyro.z));
  file.print(",");*/

  // Accelerometer
  /*sensors_event_t aevent, mevent;
  accelmag.getEvent(&aevent, &mevent);
  file.print(String(aevent.acceleration.x));
  file.print(",");
  file.print(String(aevent.acceleration.y));
  file.print(",");
  file.print(String(aevent.acceleration.z));
  file.print(",");*/

  // Magnetometer
  /*file.print(String(mevent.magnetic.x));
  file.print(",");
  file.print(String(mevent.magnetic.y));
  file.print(",");
  file.print(String(mevent.magnetic.z));
  file.print(",");*/

  // Air Pressure/temperature/humidity
  file.print(String(bme.readTemperature()));
  file.print(",");
  file.print(String(bme.readPressure() / 100.0F));
  file.print(",");
  file.print(String(bme.readAltitude(SEALEVELPRESSURE_HPA)));
  file.print(",");
  file.print(String(bme.readHumidity()));
  file.print(",");

  // Color (wind direction)
  /*uint16_t r, g, b, c, colorTemp, lux;
  tcs.setInterrupt(0);
  tcs.getRawData(&r, &g, &b, &c);
  colorTemp = tcs.calculateColorTemperature_dn40(r, g, b, c);
  lux = tcs.calculateLux(r, g, b);
  tcs.setInterrupt(1);
  file.print(String(r));
  file.print(",");
  file.print(String(g));
  file.print(",");
  file.print(String(b));
  file.print(",");*/
  
  // Light
  file.print(String(uv.readVisible()));
  file.print(",");
  file.print(String(uv.readIR()));
  file.print(",");
  float UVindex = uv.readUV();
  UVindex /= 100.0;
  file.print(String(UVindex));
  
  file.println();
  if (!file.sync() || file.getWriteError()) {error("write");}
  if (!file.close()) error("close");

  Serial.println();
  delay(SAMPLE_INTERVAL_MS);
}

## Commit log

2020-06-16 Added initial versions of logging code
    [Log_Wed_May_20_01-33-06_2020.csv, Log_Wed_May_20_01-33-06_2020.ods, Log_Wind_1.csv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]
2020-06-20 Added conversion of wind sensor readings to m/s
2020-06-20 Removed cloud upload code in enviro_logging_wind
    [Log_Sat_Jun_20_04-35-48_2020.csv]
2020-06-27 Moved datalogging files into folder
    [Log_Sat_Jun_20_04-35-48_2020.csv, Log_Wed_May_20_01-33-06_2020.csv, Log_Wed_May_20_01-33-06_2020.ods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]
2020-06-30 Update to keep anemometer board from falling asleep
2020-07-01 Updated sample logs
    [Log_Mon_Jun_29_2020.csv, Log_Mon_Jun_29_2020.ods, Log_Mon_Jun_29_2020.xlsx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]
2020-07-05 Logging code for anemometer + thermal airflow sensor
2020-07-06 Updated csv output with airflow sensor, added sample log
    [Log_Mon_Jul__6_01-06-24_2020.csv, Log_Mon_Jul__6_01-06-24_2020.ods]
2020-07-06 Added airflow sensor temperature measurement
    [Log_Mon_Jul__6_02-28-41_2020.csv, Log_Mon_Jul__6_02-28-41_2020.ods]
2020-07-07 More sample logs
    [Log_Mon_Jul__6_01-06-24_2020.csv, Log_Mon_Jul__6_01-06-24_2020.ods, Log_Mon_Jul__6_02-28-41_2020.csv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]
2020-08-18 Added code for Adafruit Feather version
    [Log_Mon_Jul__6_01-06-24_2020.csv, Log_Mon_Jul__6_01-06-24_2020.ods, Log_Mon_Jul__6_02-28-41_2020.csv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]
2020-09-15 Updated for M0 feather
    - Enabled all sensors
    - Added anemometer
2020-09-16 Removed waiting for a serial connection before starting logging
    [sample-log-01.xlsx]
2020-09-19 Pi Zero sample log for comparison with Feather log
    [Log_Wed_Sep_16_2020.csv]
2020-09-19 Feather sample logs and charts
    [DATA02.CSV, sample-log-01.xlsx, sample-log-02.xlsx]
2020-11-11 Added program for new version of pod
    Also added a test program for the SPL06-007 chip on the custom PCB.
2020-12-16 Error LEDS and battery voltage logging
2020-12-16 Radio receiver for magnet release
2021-05-11 Updated program for new version of PCB
    - Removed light/accel/gyro sensors from program
    - Changed SD card to new CS pin
    - Improved error handling and messages
    [feather-sensor-logging-v2.1.ino]
2021-05-13 Updated LED error codes
    [feather-sensor-logging-v2.1.ino]
2021-05-25 Automatic detection of installed pressure sensor type
2021-07-15 Updated error codes, added system status log
    [feather-sensor-logging-v2.1.ino]
2021-07-22 Auto-detect light sensor, ignore failed chip detect test
    [feather-sensor-logging-v2.1.ino]
2021-08-16 Auto-detect for accel/mag/gyro, print SD card status to serial monitor
2021-08-16 SD card activity LED

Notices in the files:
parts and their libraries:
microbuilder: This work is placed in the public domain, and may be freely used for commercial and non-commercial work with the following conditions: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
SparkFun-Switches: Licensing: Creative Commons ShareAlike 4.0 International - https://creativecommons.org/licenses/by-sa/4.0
